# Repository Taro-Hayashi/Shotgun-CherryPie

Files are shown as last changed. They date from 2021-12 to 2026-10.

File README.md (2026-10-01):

# Shotgun チェリーパイ ビルドガイド（[English](https://github.com/Taro-Hayashi/Shotgun-CherryPie/blob/main/README_EN.md)）
- [キット内容](#キット内容)
- [準備](#準備)
- [はんだ付け](#はんだ付け)
- [組み立て](#組み立て)
- [キーのカスタマイズ](#キーのカスタマイズ)
- [3Dプリンタ製カバーの組み立て](#3Dプリンター製カバーの組み立て)
- [その他](#その他)

## キット内容
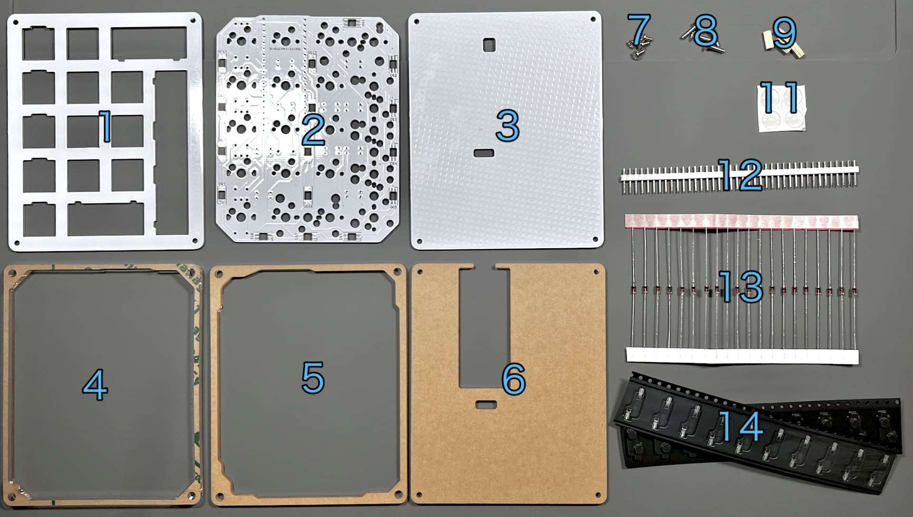
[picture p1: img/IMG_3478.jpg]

||部品名|数| |
|-|-|-|-|
|1|メインボード|1||
|2|トッププレート|1||
|3|ボトムプレート|1||
|4|ミドルプレート1|1~2|5mm厚か3mm厚|
|5|ミドルプレート2|1|3mm厚|
|6|ミドルプレート3|1|3mm厚|
|7|ネジ（短）|4|4mm|
|8|ネジ（長）|4|8mm|
|9|スペーサー|4||
|11|ゴム足|4||
|12|40Pピンヘッダ|1||
|13|ダイオード|20|1N4148|
|14|Cherry MX ホットスワップソケット|20||
|15|3Dプリンター製カバー|1||
||Raspberry Pi Pico（Type-C、互換品）|1|遊舎工房キットのみ|

2026年8月より遊舎工房さん取り扱いキットではRaspberry Pi Pico（Type-C）互換品が同梱されています。

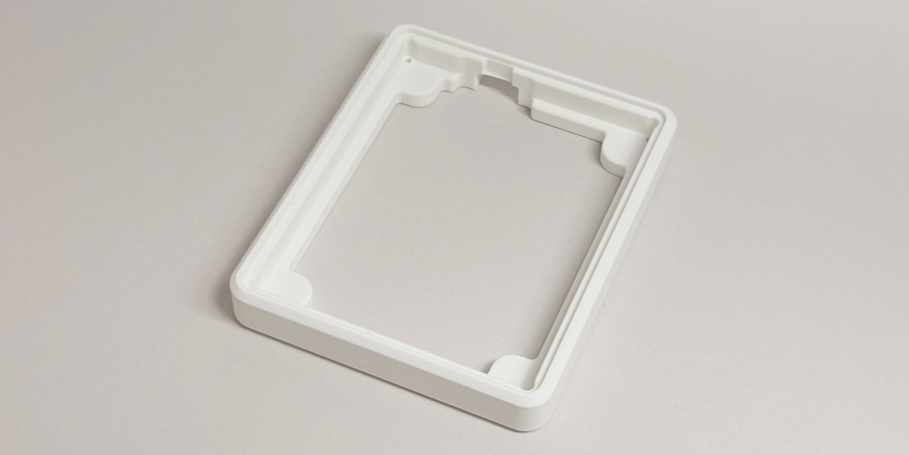
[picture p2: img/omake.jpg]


Step
- https://github.com/Taro-Hayashi/Shotgun-CherryPie/tree/main/step

### キット以外に必要なもの

リンクにはアフィリエイトリンクを含みます。

|部品名|数||
|-|-|-|
|キースイッチ（[遊舎工房](https://shop.yushakobo.jp/collections/cherry-mx-clone)、[TALPKEYBOARD](https://shop.talpkeyboard.com/collections/keyswitch?ref=tarohayashi)）|〜20|CherryMX互換|
|キーキャップ（[遊舎工房](https://shop.yushakobo.jp/collections/keycaps)、[TALPKEYBOARD](https://shop.talpkeyboard.com/collections/keycaps?ref=tarohayashi)）|〜20|スイッチに合うもの|
|USB ケーブル|1|データ転送対応のもの|
|Raspberry Pi Pico（同梱でない場合）|1|互換品には適合しないものがあります。|

### オプション

|部品名|数||
|-|-|-|
|スタビライザー（[遊舎工房](https://shop.yushakobo.jp/products/a0500st)）|必要数|2U、PCBマウント|
|ロータリーエンコーダー（[遊舎工房](https://shop.yushakobo.jp/products/3762)）|～5|EC11/EC12/ロープロファイル|
|ノブ（[遊舎工房](https://shop.yushakobo.jp/products/3733)）|〜5|外径19mmまで|
|LED SK6812MINI-E（[遊舎工房](https://shop.yushakobo.jp/products/sk6812mini-e-10)）|12、もしくは28|12個で裏面のみ、28個で両面|

### 必要な工具
|工具名|
|-|
|はんだごて|
|はんだ|
|ピンセット|
|精密ドライバー|
|ニッパー等ダイオードの足を切れるもの|

## 準備
### レイアウトを決める
このキットはいろいろなレイアウトから選んでお使いいただけます。
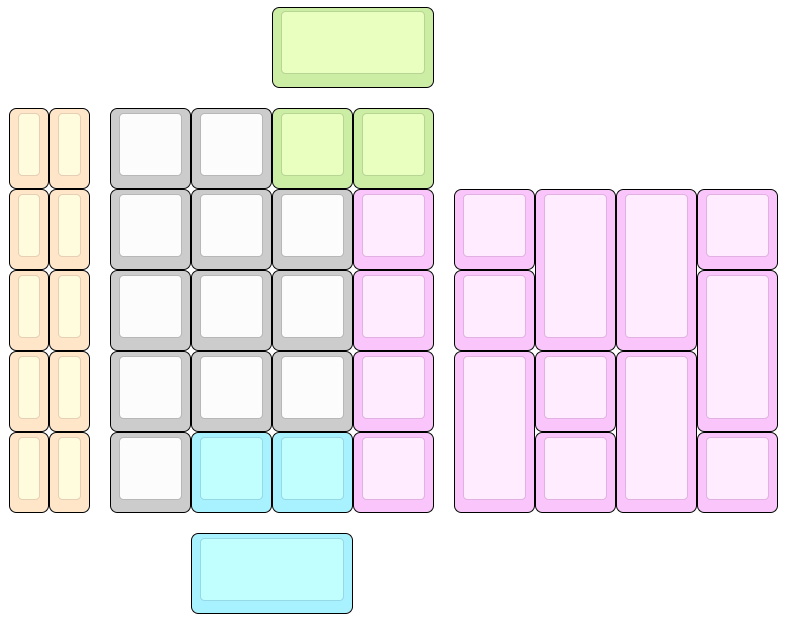
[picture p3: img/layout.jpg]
  
色のついているところが交換可能になっています。  

ビルドガイドではロータリーエンコーダーを1つ、幅が2倍（2U）のキーを二つ使ったテンキーにします。  
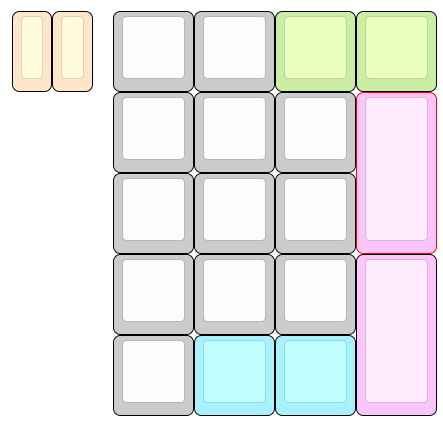
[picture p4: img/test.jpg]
    
キット、その他必要なものに追加でロータリーエンコーダーとノブを一つずつ、スタビライザーを2つ用意しました。  
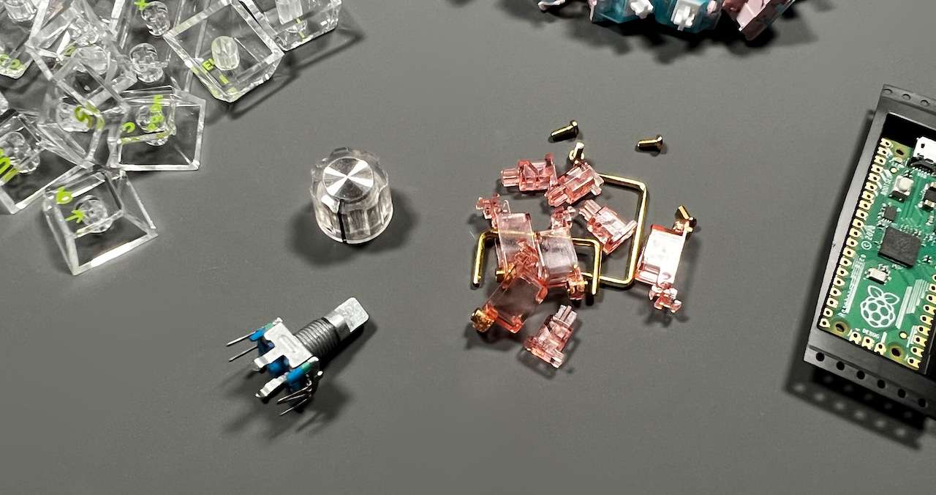
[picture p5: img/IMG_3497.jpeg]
    

### テスト用ファームウェアの書き込み
こちらからテスト用ファームウェアをダウンロードしてください。
 - https://github.com/Taro-Hayashi/Shotgun-CherryPie/releases/latest/download/tarohayashi_shotgun_cp_default.uf2

Raspberry Pi Picoを、BOOTSELボタン押しながらUSBケーブルでPCと接続すると、RPI-RP2というUSBメモリとして認識されます。
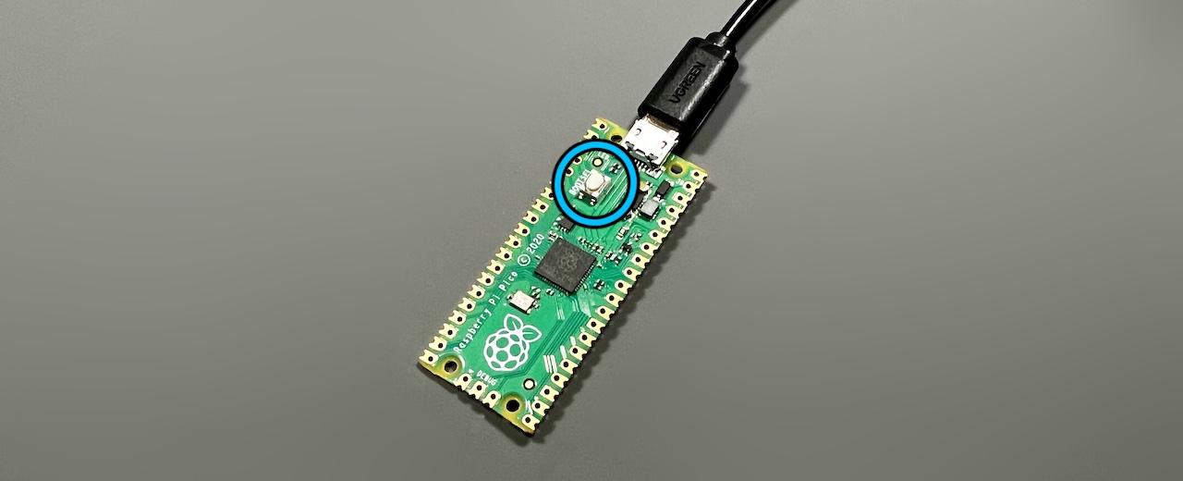
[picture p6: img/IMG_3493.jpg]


ここにダウンロードしたuf2ファイルを書き込むと、Raspberry Pi Picoをキーボードとして使えるようになります。

書き込みが終わったら一旦USBケーブルは外します。

## はんだ付け
はんだ付けのやり方は動画で見るとわかりやすいです。
パーツは思ったより壊れないので落ち着いて作業すると失敗しにくいです。

 - ホームセンターのDCMさんの解説動画(58秒～)

(https://www.youtube.com/watch?v=JFQg_ObITYE&t=58s)

### LEDのはんだ付け（オプション）
LEDを取り付ける場合はメインボードに最初にはんだ付けします。
 - [LEDの取り付け方](led.md)

後からでも可能ですが他の部品にこてが当たり溶かしてしまう可能性があります。

### ダイオードのはんだ付け

D1~D20まで取り付けます。
足を曲げて裏から差し込みます。
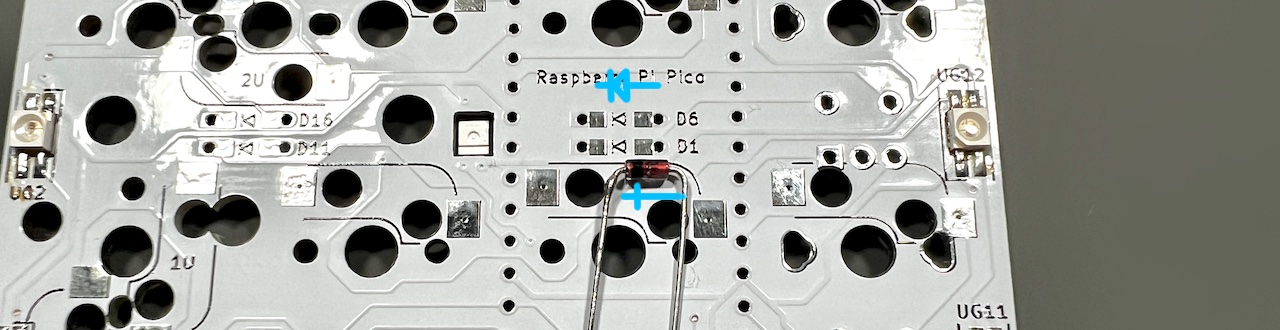
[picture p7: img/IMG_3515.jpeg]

ダイオードには向きがあります。三角形の先の棒と黒線を合わせましょう。

表で更に足を曲げて抜けないようにします。
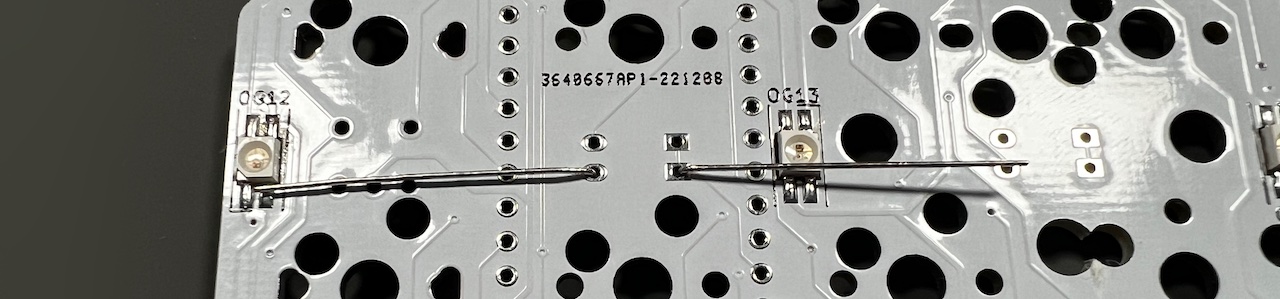
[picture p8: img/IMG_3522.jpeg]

ダイオードと並行に曲げるとあとでキースイッチに干渉しにくいです。

はんだ付けをして足を切ります。
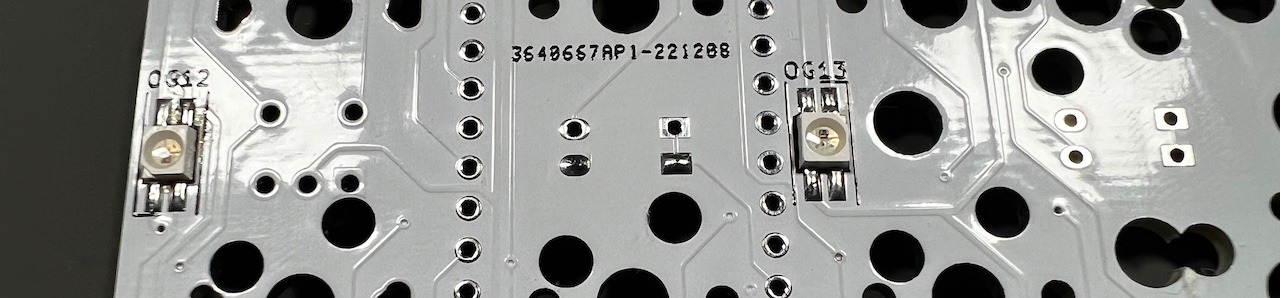
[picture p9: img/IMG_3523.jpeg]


### ソケットのはんだ付け
使うソケットのパッドにソケットを乗せます。
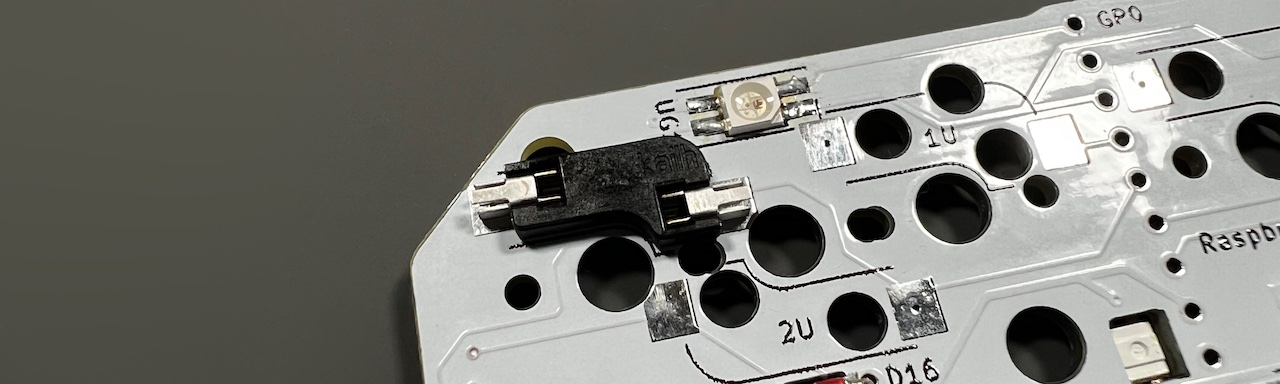
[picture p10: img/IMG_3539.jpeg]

ソケットを置いたらピンセットで押さえつけながらはんだを注いでいきます。入り組んでいて表面積が多いので多めに必要になります。
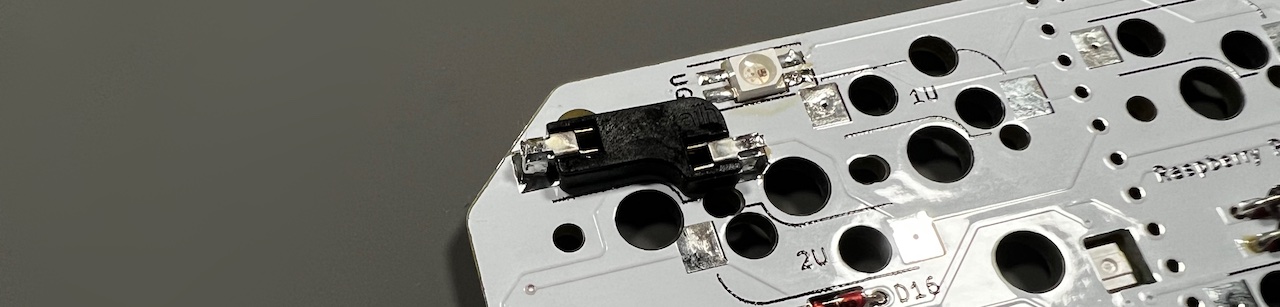
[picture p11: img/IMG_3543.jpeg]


裏から見ると左右が逆になっているのでレイアウトに注意してソケットの位置を決めます。
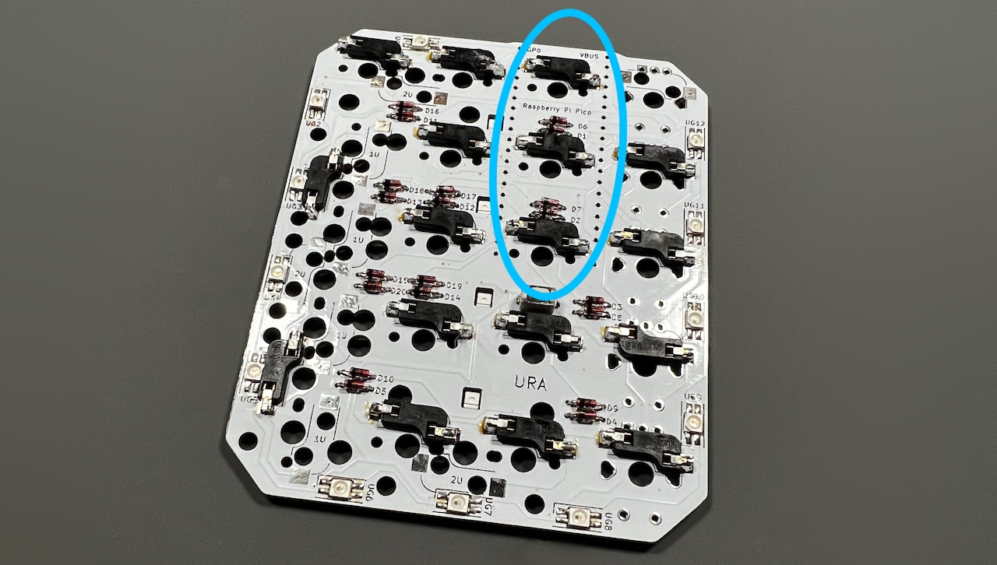
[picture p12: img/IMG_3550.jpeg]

青枠の部分にあるソケットは基板になるべく密着するようにはんだ付けしてください。

### （オプション）ロータリーエンコーダーのはんだ付け
足を折らないようにホールに通します。
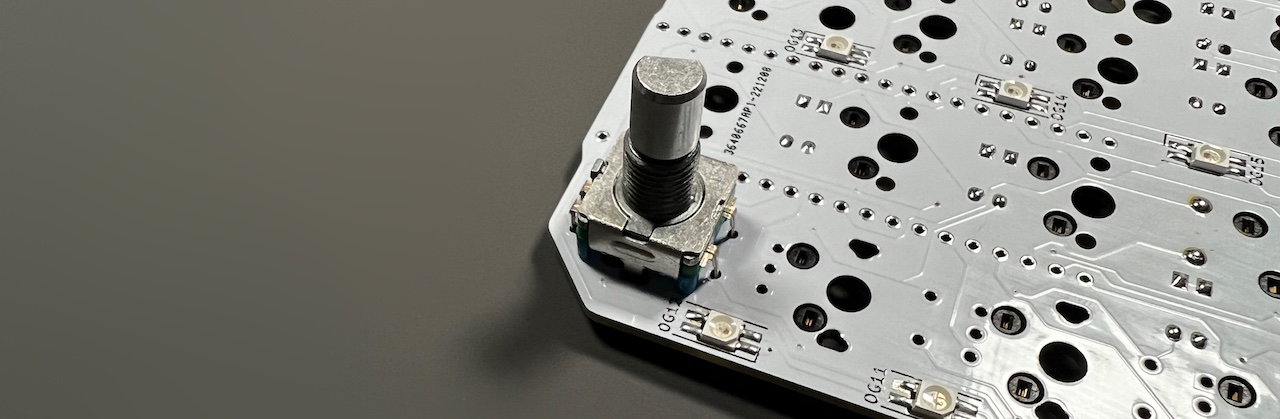
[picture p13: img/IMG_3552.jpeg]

あとで場所を変更する可能性があるときはクリップの部分ははんだ付けしなくても大丈夫です。
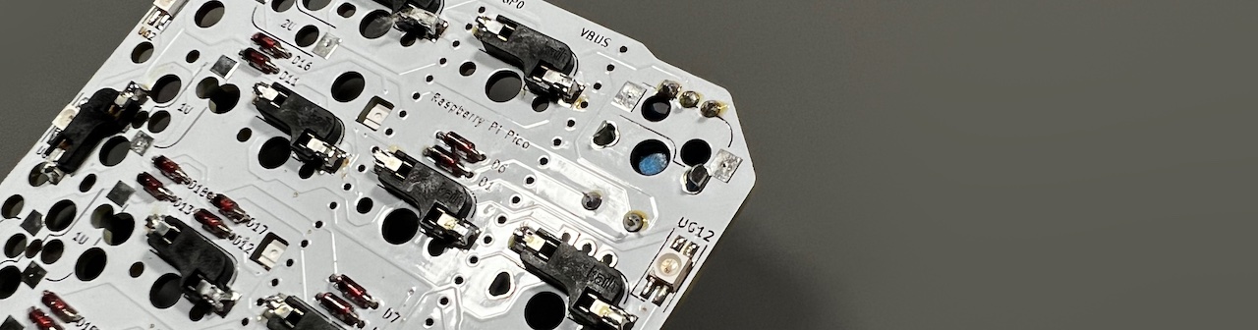
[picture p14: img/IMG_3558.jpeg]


### Raspberry Pi Picoのはんだ付け
ピンヘッダを20ピンずつに切るか折るかします。
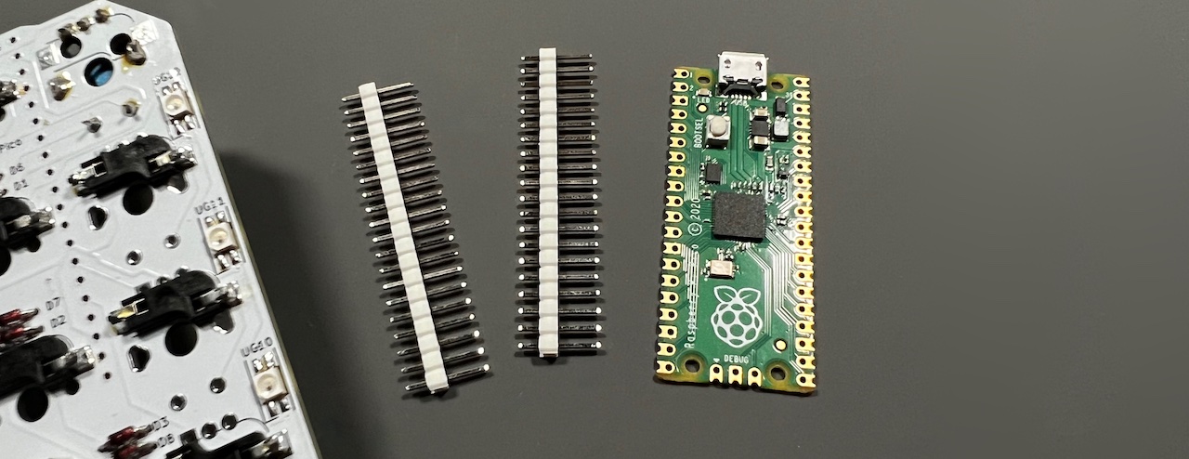
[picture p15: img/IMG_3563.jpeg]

Raspberry Pi Picoを取り外せなくなるので隠れてしまうダイオードの方向やソケットのはんだ付けを改めて確認してください。

ピンヘッダを基板に立てます。どちら側でも構いませんが長い方を挿しました。
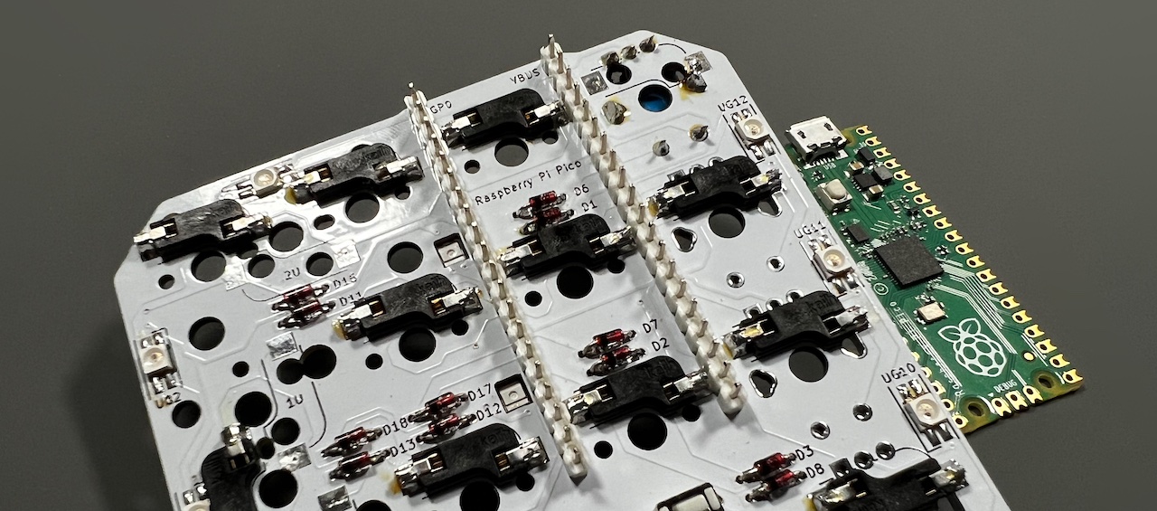
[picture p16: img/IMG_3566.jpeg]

GP0、VBUS位置を合わせてRaspberry Pi Picoを乗せ、はんだ付けします。
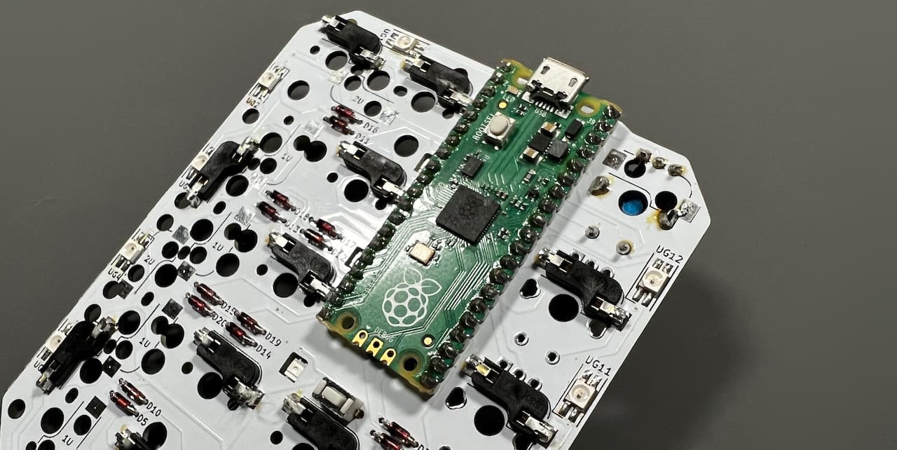
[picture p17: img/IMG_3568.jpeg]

表面の足を切りはんだ付けします。
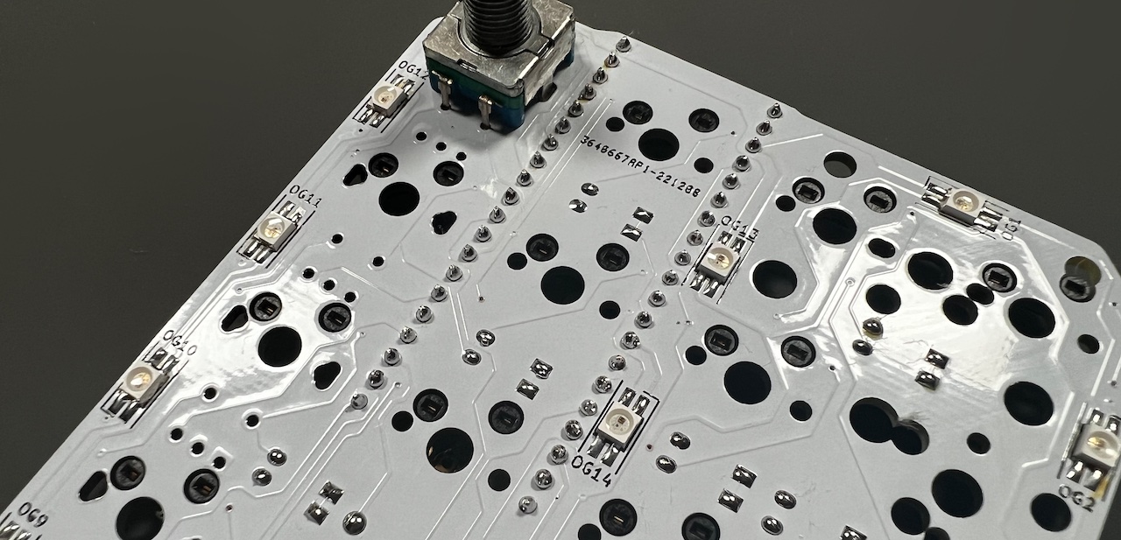
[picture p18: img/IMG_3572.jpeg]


### 動作確認
Raspberry Pi PicoにUSBケーブルを繋ぎます。
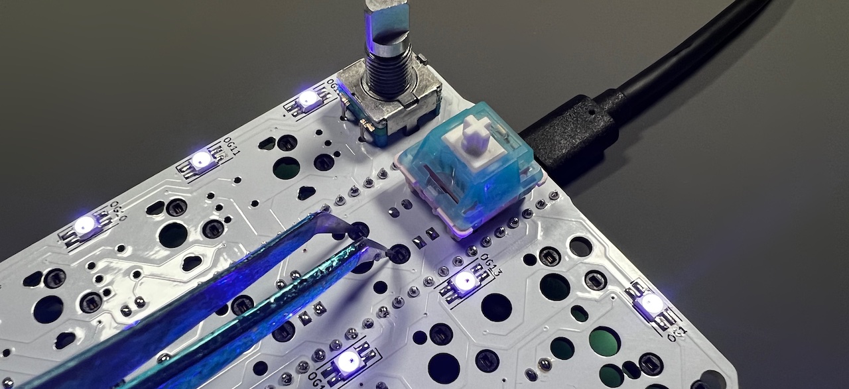
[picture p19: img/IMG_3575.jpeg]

ソケットをピンセットで短絡したり、スイッチを挿して押したりしてキーが入力されるか調べます。

問題がなければはんだ付けは終了です。お疲れ様でした。

## 組み立て
### （オプション）スタビライザーの組み立てと取り付け
スタビライザーがあると2Uのキーの押下が安定します。無くても使えるのでお好みでお使いください。

小さい方のパーツの穴が二つ開いている側を、大きいパーツの穴が開いている方向に合わせて組み合わせます。
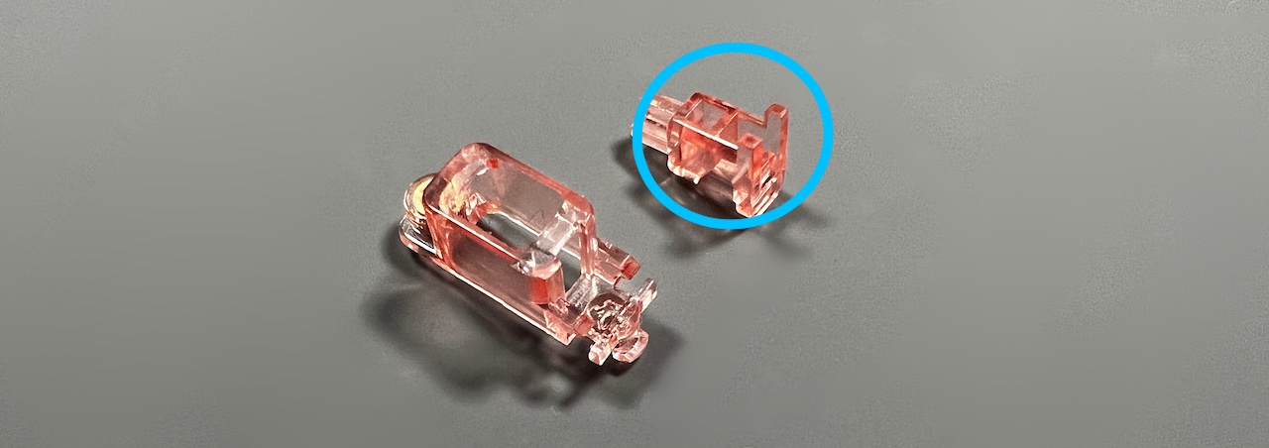
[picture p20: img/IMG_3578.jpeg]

金属の棒を下の穴に差し込みツメにパチっと音がするまで押し込んで完成です。
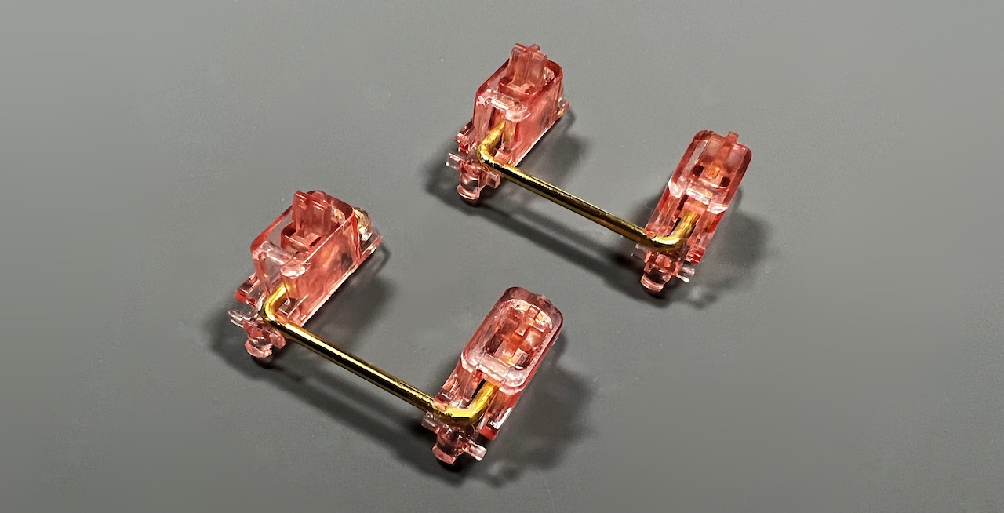
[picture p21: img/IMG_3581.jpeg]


基板の大きい方の穴にツメをひっかけながら取り付けます。
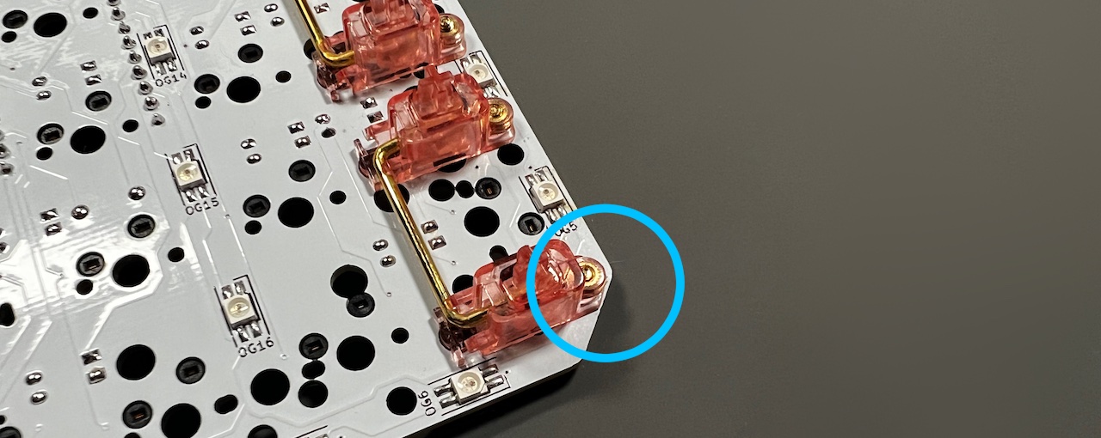
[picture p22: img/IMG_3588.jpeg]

角にスタビライザーを付けるとケースと干渉するためニッパーで切り落としています。

### プレートの取り付け
傷が付かないように裏返しに組み立てられて梱包されているので一度すべてのネジ、スペーサーを外してください。
アクリルプレートからは保護フィルムをはがします。割れやすいパーツもあるので気をつけてください。

メインボードにトッププレートを乗せます。裏表、上下左右に気を付けましょう。

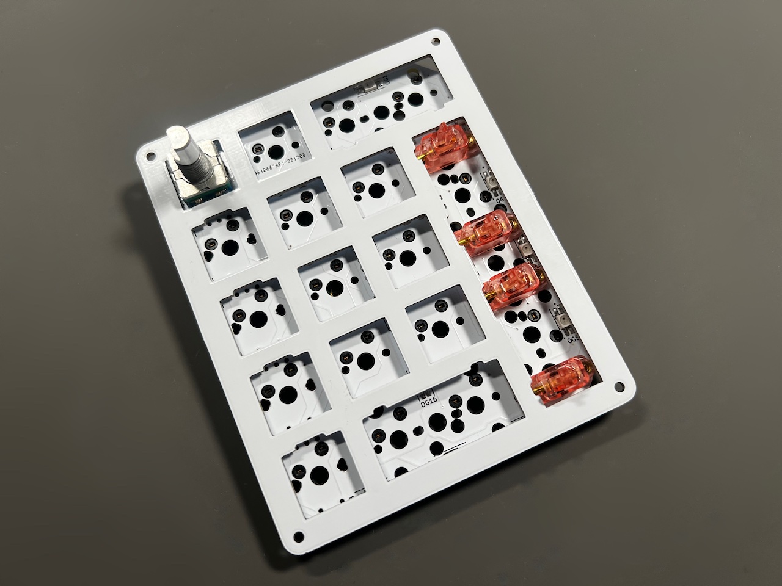
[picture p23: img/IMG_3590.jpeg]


隅のキースイッチから差し込んで、トッププレートにツメを咬ませます。
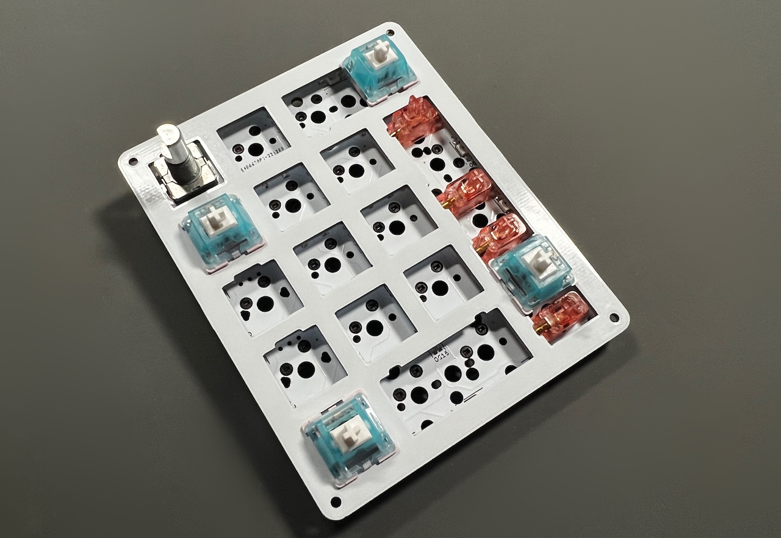
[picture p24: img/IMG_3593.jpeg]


全てのスイッチを取り付けました。
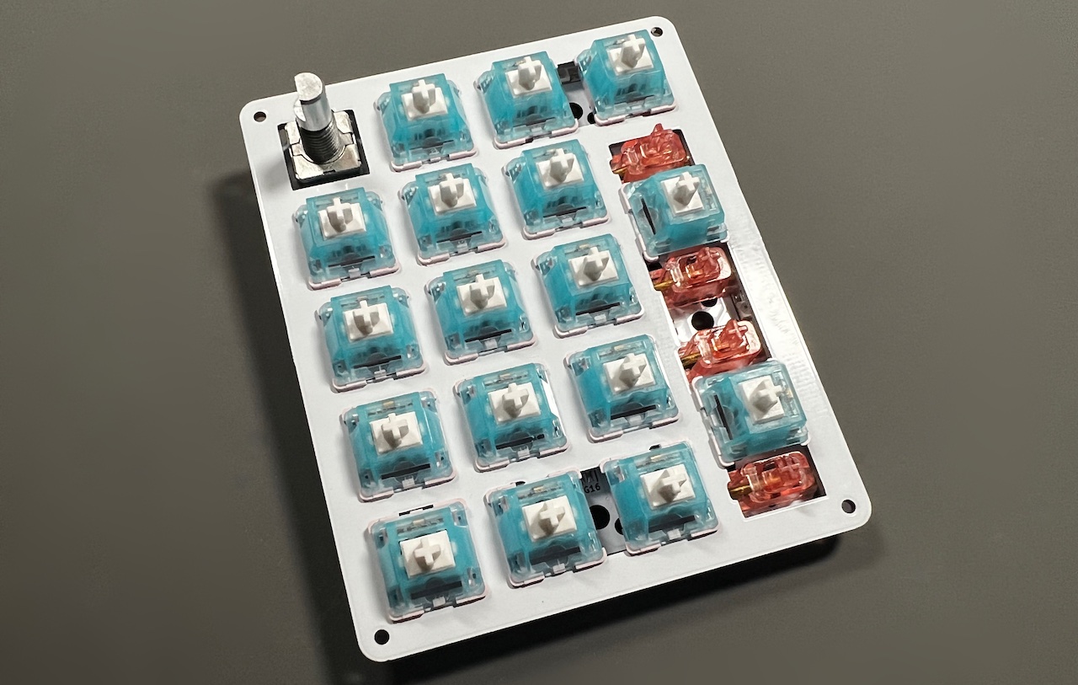
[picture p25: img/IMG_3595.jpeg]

トッププレートは浮いていますが、スイッチのツメに引っかかっているため安定しているはずです。

裏返して4隅にスペーサーを、ネジ（短）で取り付けます。
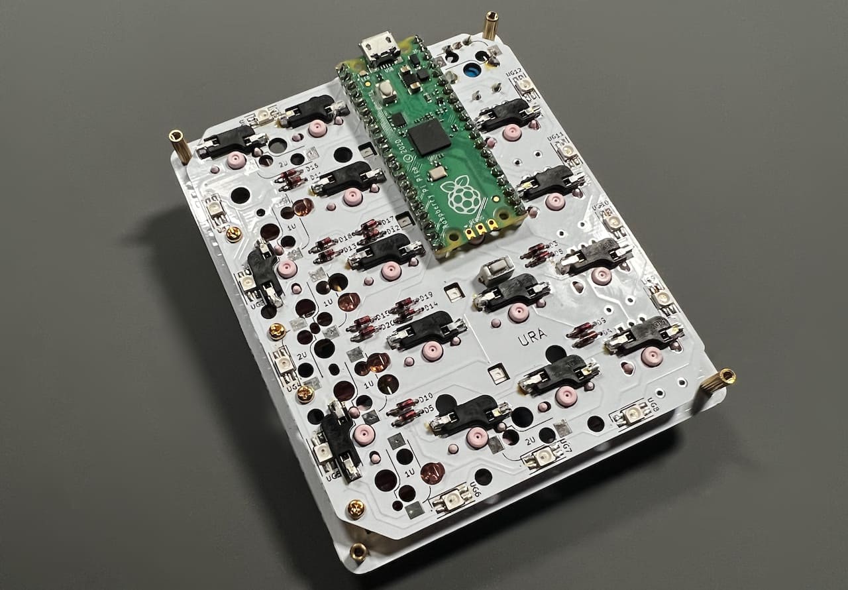
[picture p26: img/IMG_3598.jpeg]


ミドルプレート1（5mm厚1枚、もしくは3mm厚が2枚、穴が長方形に近い）、ミドルプレート2（3mm厚、穴が少し狭い）の順にスペーサーに通します。

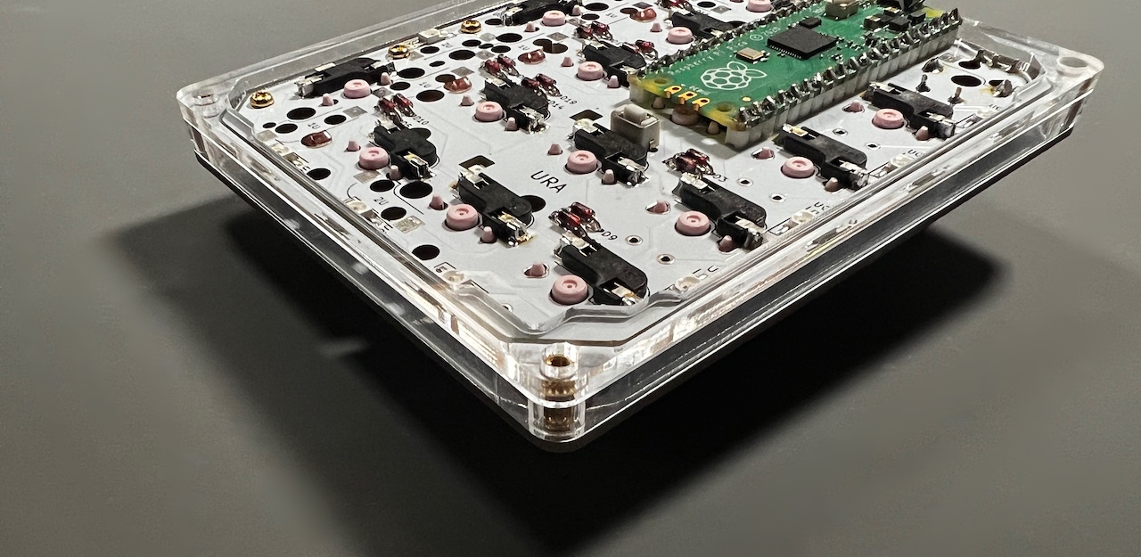
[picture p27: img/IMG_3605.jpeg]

Raspberry Pi PicoのUSB端子を避ける時に割れないように気を付けてください。

ミドルプレート3を乗せます。
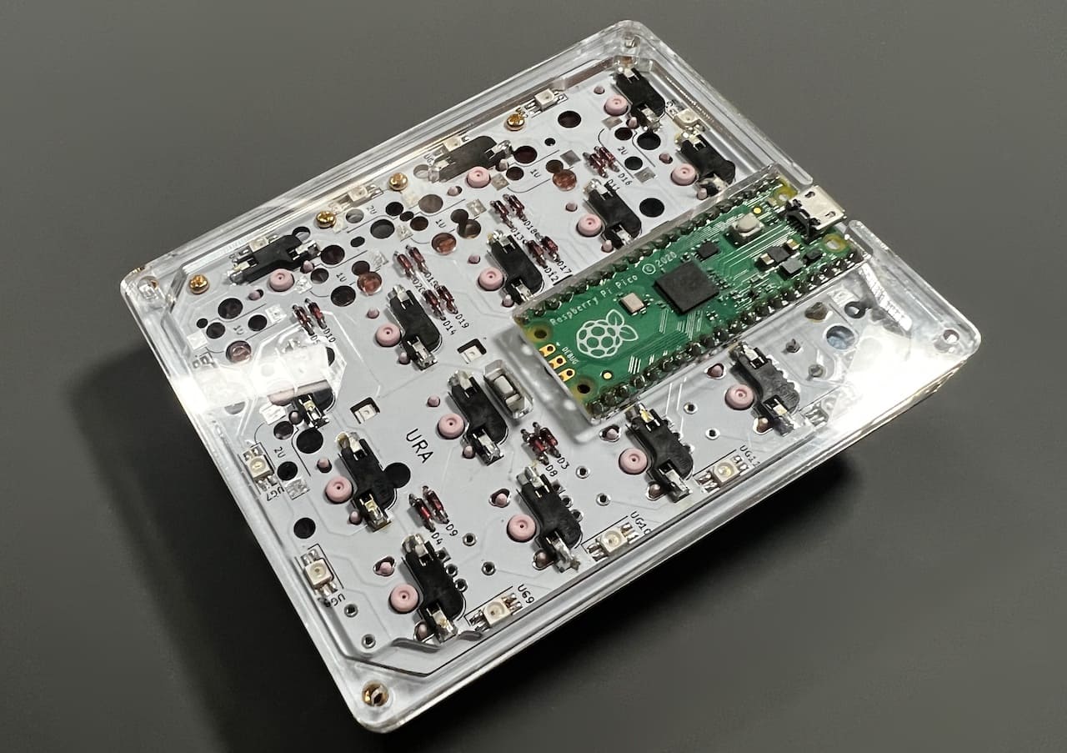
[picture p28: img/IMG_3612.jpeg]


バックプレートをネジ（長）で組付けてゴム足を4隅に貼ります。
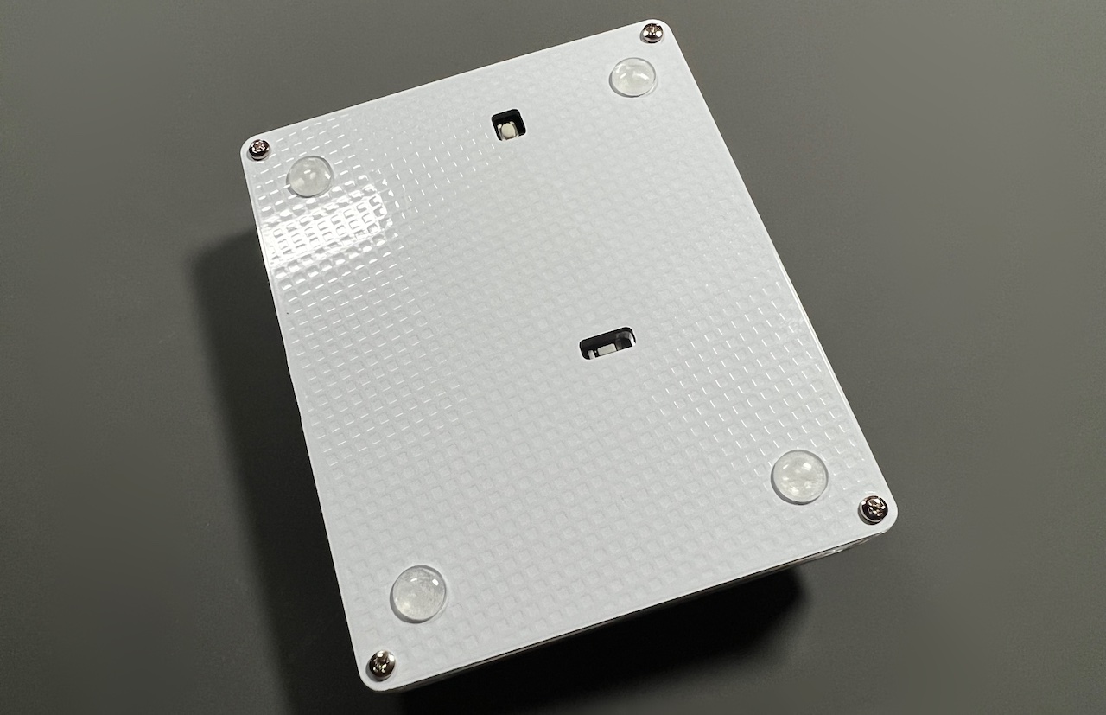
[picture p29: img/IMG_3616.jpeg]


キーキャップを乗せたら組み立ては終了です。
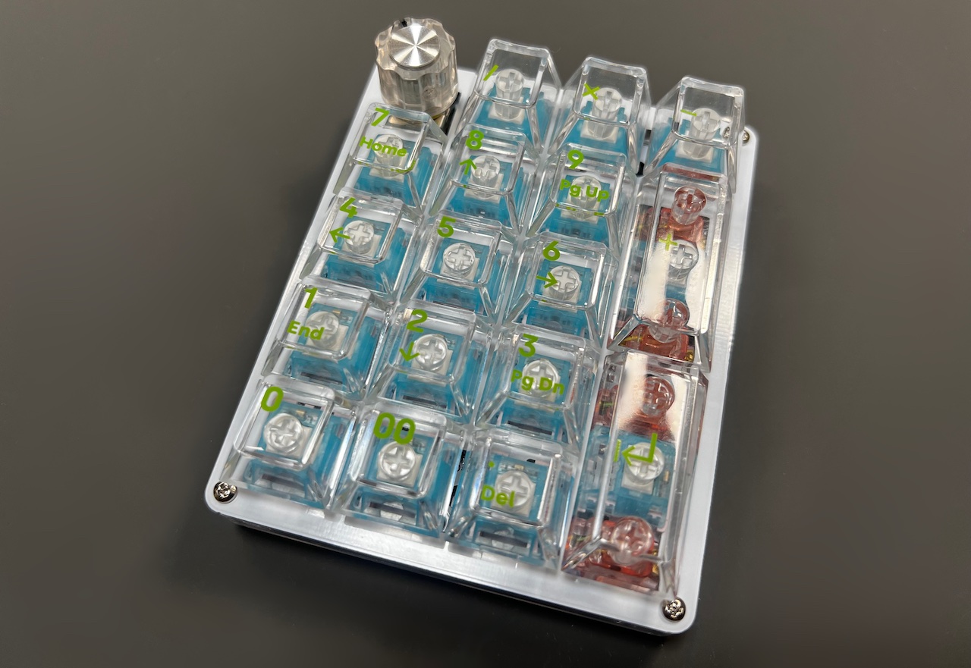
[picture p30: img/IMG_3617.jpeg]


早速USBケーブルでPCと接続してRemap用ファームウェアを書き込みましょう。
 - https://github.com/Taro-Hayashi/Shotgun-CherryPie/releases/latest/download/tarohayashi_shotgun_cp_via.uf2

裏面のスリットからリセットボタンを押すか、USBのすぐ下のキーを押しながらケーブルを接続して2秒待ってから離すとRPI-RP2フォルダを出すことができます。

## キーのカスタマイズ
RemapにGoogle ChromeかMicrosoft Edgeでアクセスしてください。
- Remap https://remap-keys.app

左を選んで進んでいくとアドレスバーからメッセージが出てキーボードを選択できます。
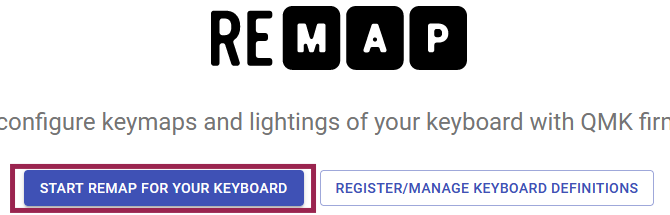
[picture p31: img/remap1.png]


ドラッグアンドドロップでキーマップの変更が終わったら右上のflashボタンを押すと反映されます。


### キーのサイズを合わせる
レイアウトオプションから2Uキーの設定をすることができます。
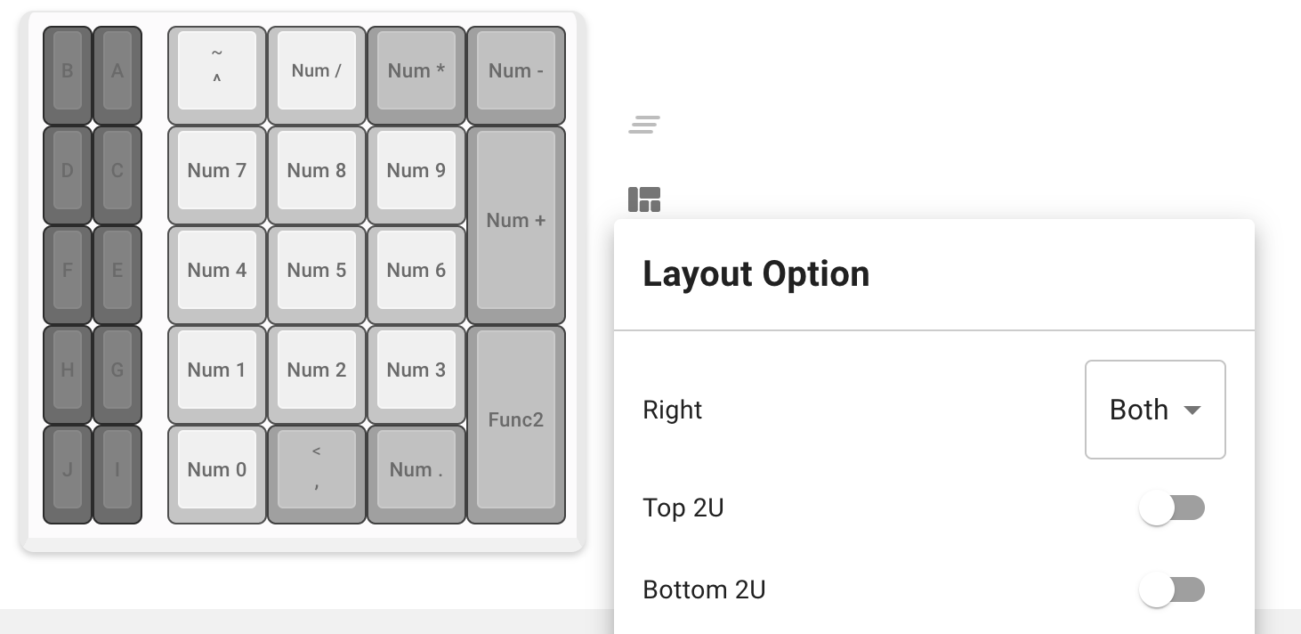
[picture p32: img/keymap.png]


### 特殊なキーを設定する
FUNCTIONSタブのVIA USER KEYにあらかじめ用意されたショートカットキーがあります。
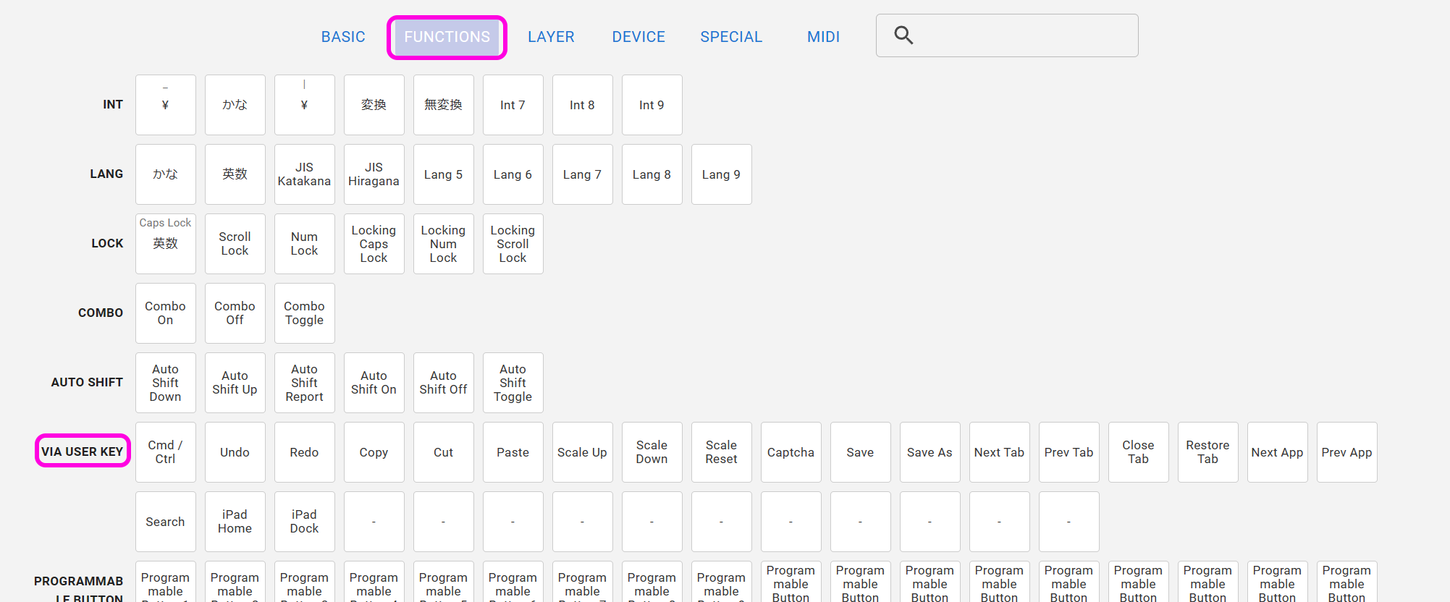
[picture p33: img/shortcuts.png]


### キーマップの保存と復元
⇔アイコンで作ったキーマップを保存することができます。
いくつかサンプルをご用意しました。自分のレイアウトを公開することもできるので是非お試しください。
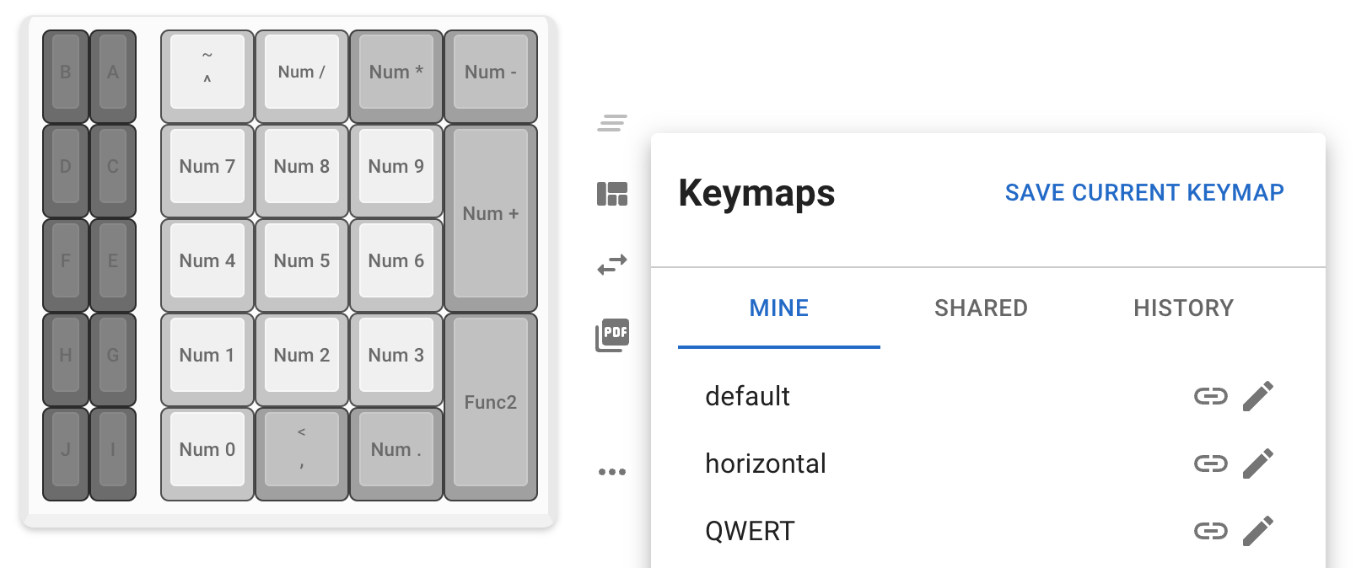
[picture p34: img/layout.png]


## 3Dプリンター製カバーの組み立て
お好みで3Dプリンター製のカバーもご利用いただけます。
スイッチプレートに短いネジでスペーサーを付けた状態にします。
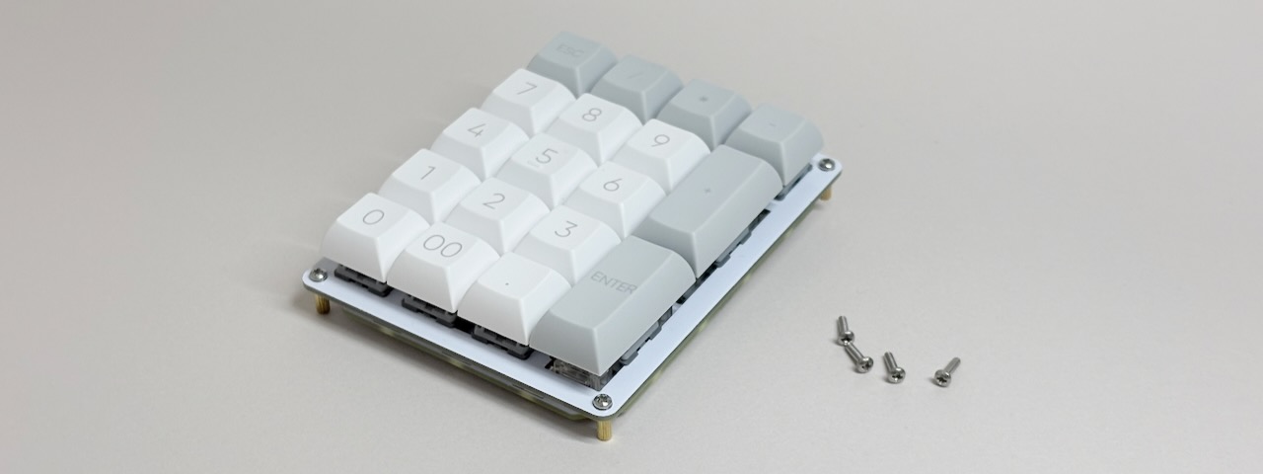
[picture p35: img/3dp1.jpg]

ケースに入れて裏面でネジ止め、ゴム足を貼ります。
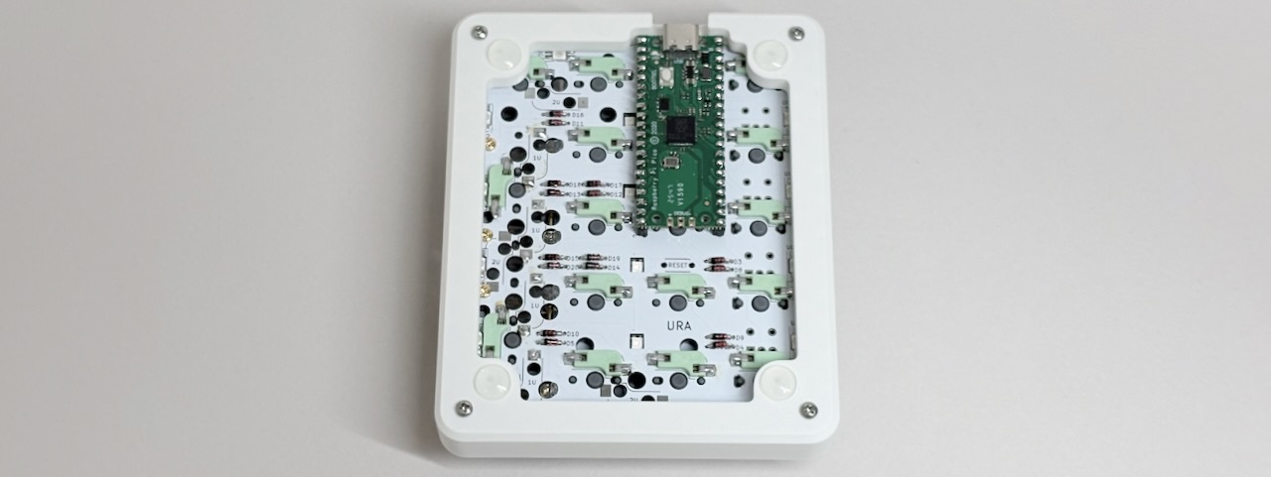
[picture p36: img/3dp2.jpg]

完成です。
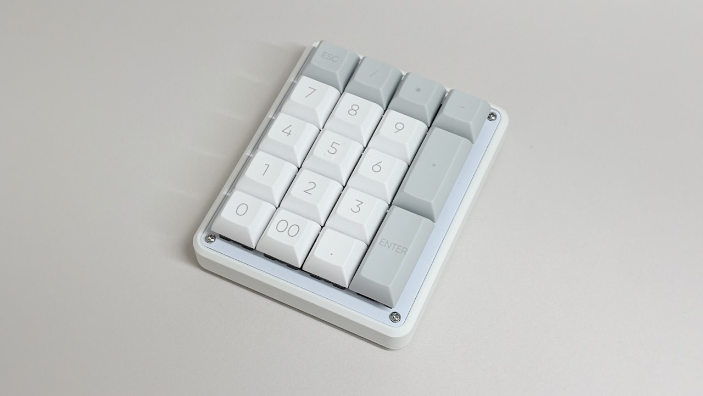
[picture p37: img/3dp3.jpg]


## その他

### PRK Firmware
Paspberry Pi Picoをキーボードとして扱う方法は他にも複数あります。PRK Firmwareはその一つでキー入れ替えの試行錯誤が手軽なところが特徴です。
- [PRK Firmware](https://github.com/picoruby/prk_firmware/)

### ファームウェアのコード
 - [qmk_firmware](qmk_firmware)

### 3Dプリント製カバーのデータ
- https://github.com/Taro-Hayashi/Shotgun-CherryPie/tree/main/step

### プレートのデータ
 - [shotgun_cp_plates.zip](https://github.com/Taro-Hayashi/Shotgun-CherryPie/releases/latest/download/shotgun_cp_plates.zip)

### アクリル積層ケース
 - [Shotgun チェリーパイ アクリル積層ケース](AcrylicCase/README.md)

### 謝辞
foostan様のフットプリントを流用、改変して使わせていただきました。
https://github.com/foostan/kbd/
https://github.com/foostan/kbd/blob/master/LICENSE

yoichiro様のフットプリントを流用、改変して使わせていただきました。
https://github.com/yoichiro/yoichiro-kbd
https://github.com/yoichiro/yoichiro-kbd/blob/main/LICENSE

せきごん様がGPIO15を使っている場合でも正常に動くようにしてくださいました。
https://github.com/sekigon-gonnoc/qmk_firmware/tree/rp2040

hasumikin様がPRK Firmwareでロータリーエンコーダーを複数個使用できるようにして、感度も上げてくださいました。
https://github.com/picoruby/prk_firmware/

### 販売サイト
- BOOTH: https://tarohayashi.booth.pm/items/3430753
- 遊舎工房: https://shop.yushakobo.jp/products/3415

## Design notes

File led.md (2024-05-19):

## LEDの取り付け方
  
裏面だけ光らせたい場合はUG1～12の12個、表面も光らせたい場合はOG1～16も合わせた28個をはんだ付けします。  
  
端子同士がくっつきやすいので、LEDのはんだ付けにはフラックスを使います。  
はんだ付けの難易度がとても下がるため私はLED以外にも毎回使っています。  
ベタつくのでフラックスクリーナーやIPA（イソプロピルアルコール）で掃除をすると綺麗になります。  
  
まずは裏面のUG1～12を取り付けます。  
LEDの切り欠きとシルク印刷のコーナーを合わせてはんだ付けしましょう。  
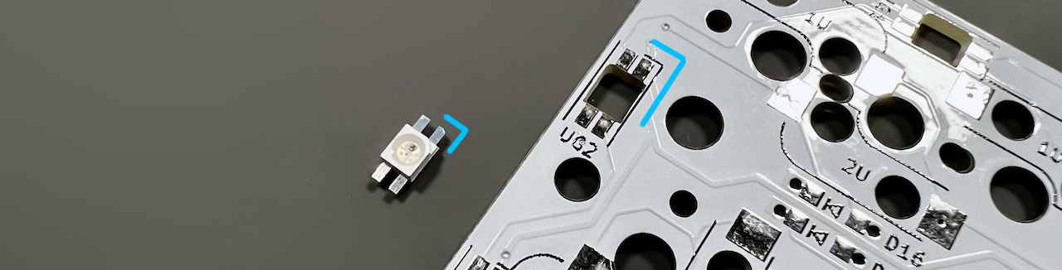
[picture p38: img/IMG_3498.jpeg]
    
向きがバラバラなので毎回確認してください。方向を間違えるとショートしてしまってキーボード自体が動きません。  

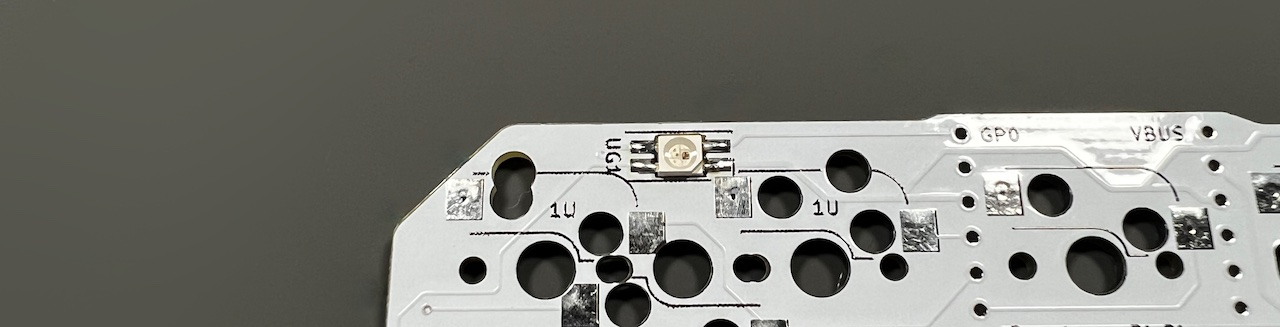
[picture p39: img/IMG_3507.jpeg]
    
両側のランドにはんだを乗せやすいようにLEDは中央に置くことを意識するといいと思います。  

裏面が終わったら表面のOG1～16を取り付けます。  
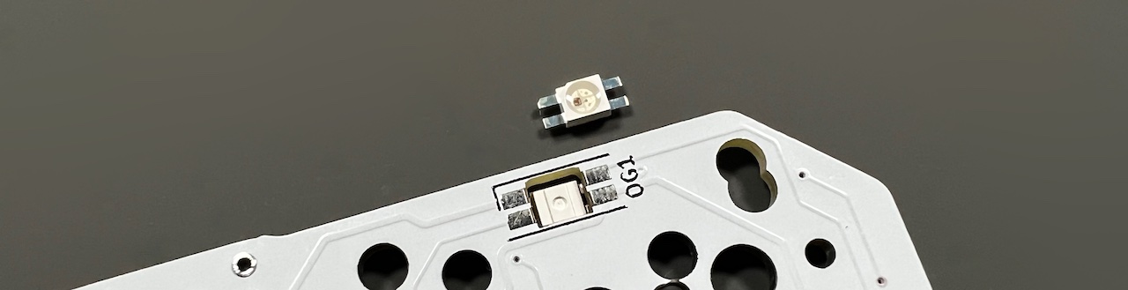
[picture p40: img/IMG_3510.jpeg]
  
一部はUGと共通の穴を使っています。  

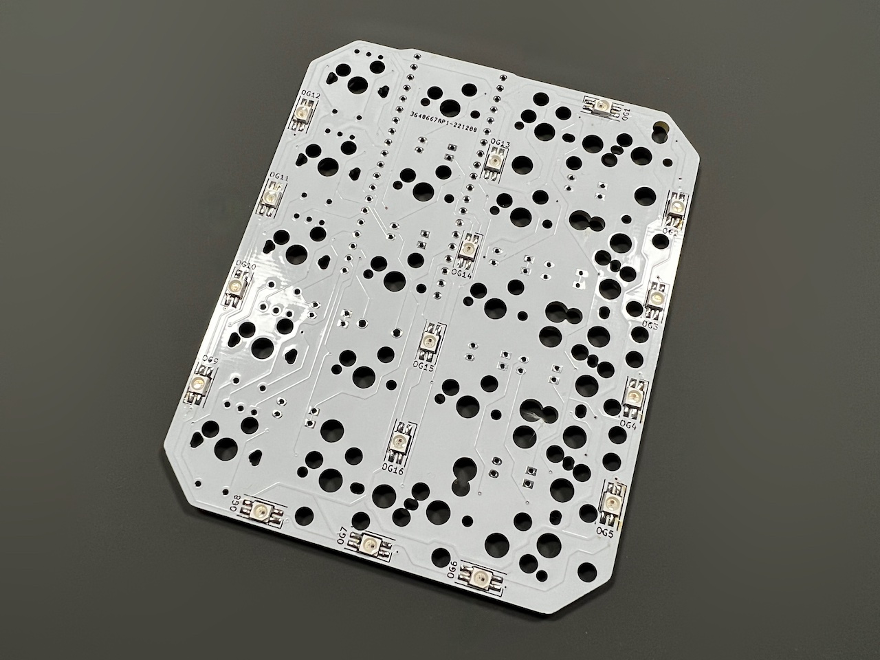
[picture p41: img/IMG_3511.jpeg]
  
  
ブラウザの機能で戻ってください。

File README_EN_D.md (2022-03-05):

# Shotgun チェリーパイ Build Manual（[日本語](https://github.com/Taro-Hayashi/Shotgun-CherryPie/blob/main/README.md)）
- [Contens](#Contens)
- [Preparation](#Preparation)
- [Soldering](#Soldering)
- [Assembling](#Assembling)
- [Customise](#Customise)

## Contents
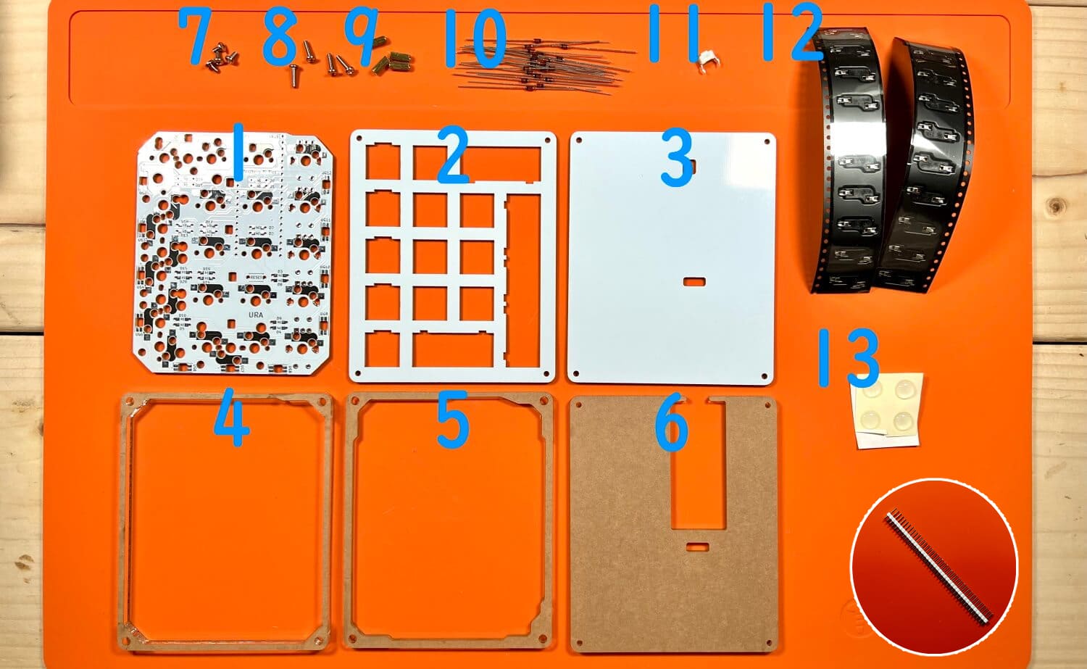
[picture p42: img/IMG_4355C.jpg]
  
||Name|Quamtities| |
|-|-|-|-|
|1|Mainboard|1|
|2|Top plate|1||
|3|Bottom plate|1||
|4|Middle plate #1|1||
|5|Middle plate #2|1||
|6|Middle plate #3|1||
|7|Short screws|4|4mm|
|8|Long screws|4|8mm|
|9|Spacers|4|8mm|
|10|Diodes|20|1N4148|
|11|Tactile switch|1||
|12|Hotswap socket|20||
|13|Rubber feet|4||
|-|Pin header|1||

### Additional required
|Name|Quantities|||
|-|-|-|-|
|Raspberry Pi Pico|1||[Yushakobo](https://shop.yushakobo.jp/en/products/raspberry-pi-pico)|
|Switches|11 - 20|Cherry MX|[Yushakobo](https://shop.yushakobo.jp/en/collections/all-switches/cherry-mx-%E4%BA%92%E6%8F%9B-%E3%82%B9%E3%82%A4%E3%83%83%E3%83%81)|
|Keycaps|11 - 20|Cherry MX|[Yushakobo](https://shop.yushakobo.jp/en/collections/keycaps/cherry-mx-%E4%BA%92%E6%8F%9B-%E3%82%AD%E3%83%BC%E3%82%AD%E3%83%A3%E3%83%83%E3%83%97)|
|Micro-USB Cable|1||[Yushakobo](https://shop.yushakobo.jp/en/products/usb-cable-micro-b-0-8m)|

### Optional
|Name|Quantities|||
|-|-|-|-|
|Conthrough|2|[Usage](https://github.com/Taro-Hayashi/Shotgun-CherryPie/blob/main/conthrough2_EN.md)|[Yushakobo](https://shop.yushakobo.jp/en/products/31?_pos=1&_sid=ca92edae3&_ss=r&variant=40815837610145)|
|Stabilizer||2U, PCB mounted|[Yushakobo](https://shop.yushakobo.jp/en/collections/all-keyboard-parts/Stabilizer)|
|Rotary emcoders||EC11/EC12||
|knobs||Outer diameter up to 19mm||
|SK6812MINI-E|28||[Yushakobo](https://shop.yushakobo.jp/en/products/sk6812mini-e-10)|

## Preparation
### Determine key layout  
This kit has a variety of layouts to choose from.  
   

In this manual, we use rotary encoder and 2 2U keys.  
    
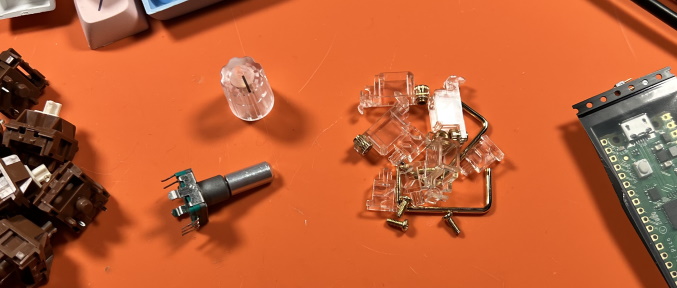
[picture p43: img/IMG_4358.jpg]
   

### Write firmware
Download PRK Firmware.
 - [Releases・picoruby/prk_firmware](https://github.com/picoruby/prk_firmware/releases)  

Click "Assets"
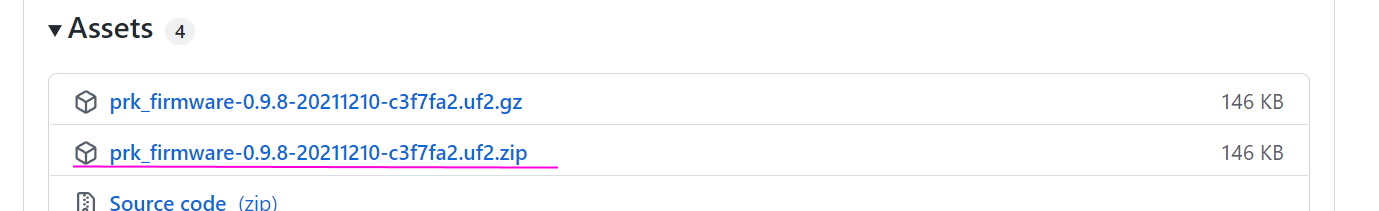
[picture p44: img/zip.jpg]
 

Connect the Raspberry Pi Pico to the PC while holding down the BOOTSEL button, it will be recognized as a USB memory device called RPI-RP2.    
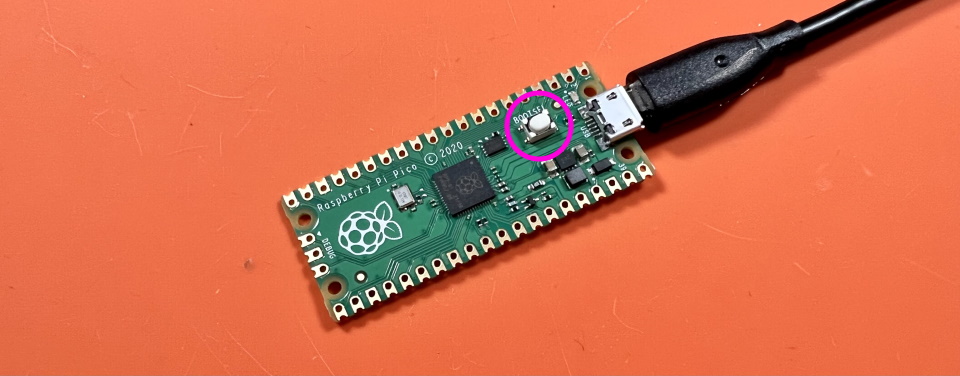
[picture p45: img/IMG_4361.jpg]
   
   
Writing the uf2 file, it will automatically reboot and be recognized as a drive called PRK Firmware.  
   
Drag and drop this keymap.rb onto the drive.
 - [keymap.rb](https://github.com/Taro-Hayashi/Shotgun-CherryPie/releases/download/0.1/keymap.rb)  

Detouch the USB cable.

## Soldering

### LED
If use LED, install first.  
 - [LED Installation](led_EN.md)  

### Diodes and tactile switch

Install the diodes from D1 to D20.
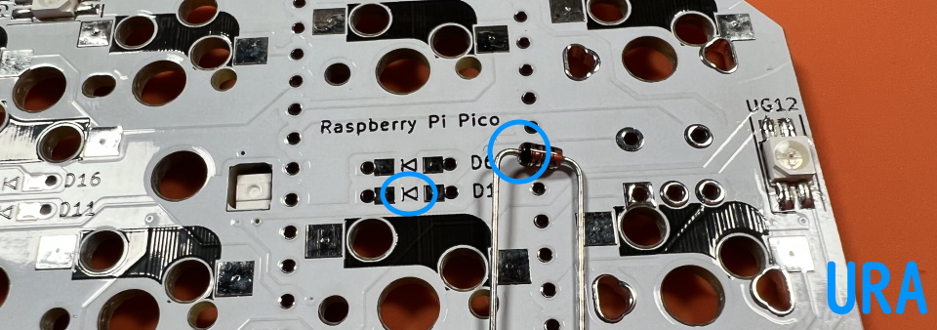
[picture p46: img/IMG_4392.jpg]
   
Diodes have a direction.  
  
Bend the legs parallel to the diode to prevent interference with the key switch later.  
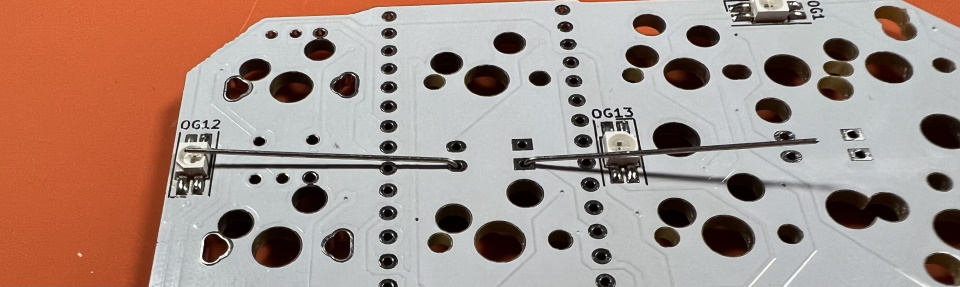
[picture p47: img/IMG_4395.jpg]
   
  
Solder and cut the legs.  
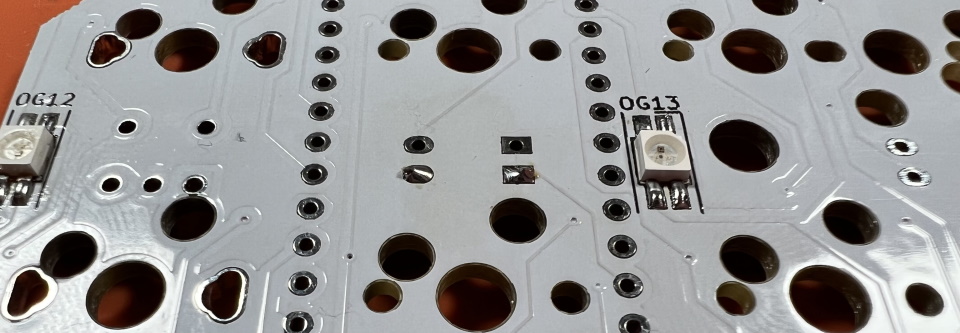
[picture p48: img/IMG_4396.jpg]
   
  
Solder Tactile Switches.   
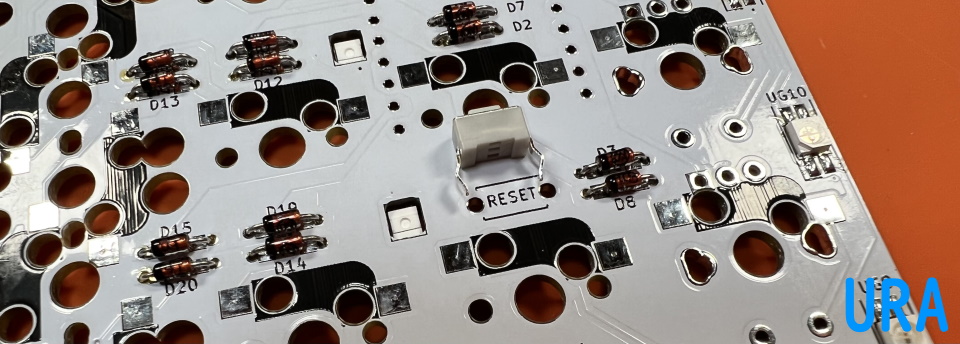
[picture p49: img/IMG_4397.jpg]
   

### Hotswap sockets
Apply a thin layer of solder beforehand.  
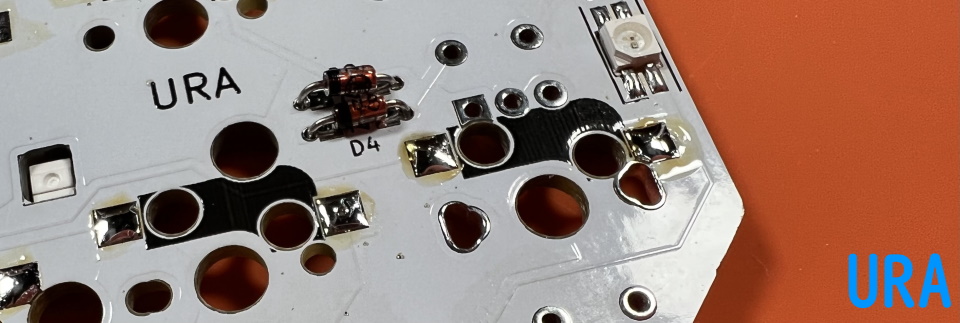
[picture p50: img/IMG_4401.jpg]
    
Solder sockets.  
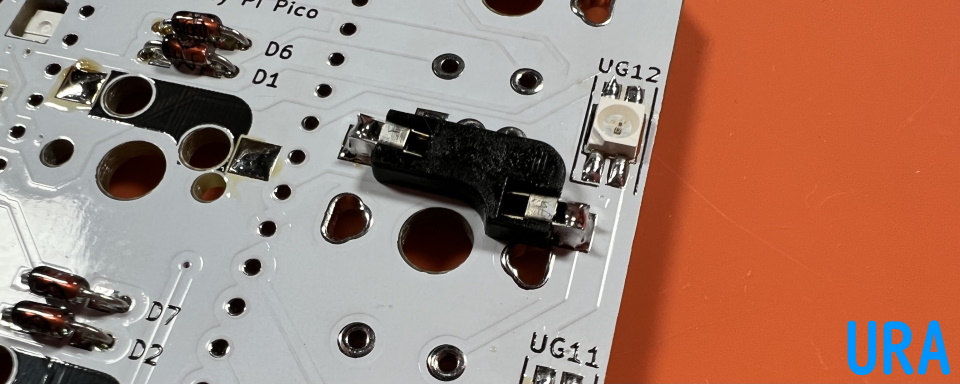
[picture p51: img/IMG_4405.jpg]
     

Be careful to keep the socket close to the board at the blue frame.  
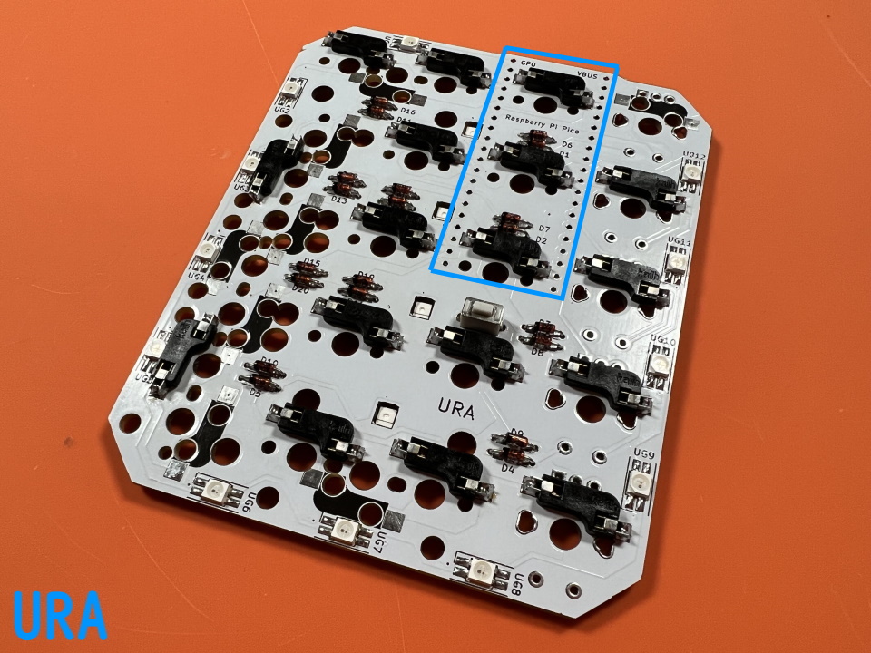
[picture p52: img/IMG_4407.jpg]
   

### Rotary encoder  
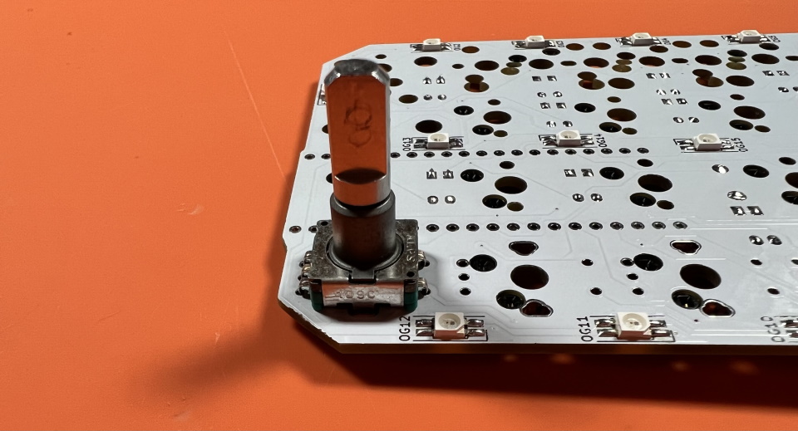
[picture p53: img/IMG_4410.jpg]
     
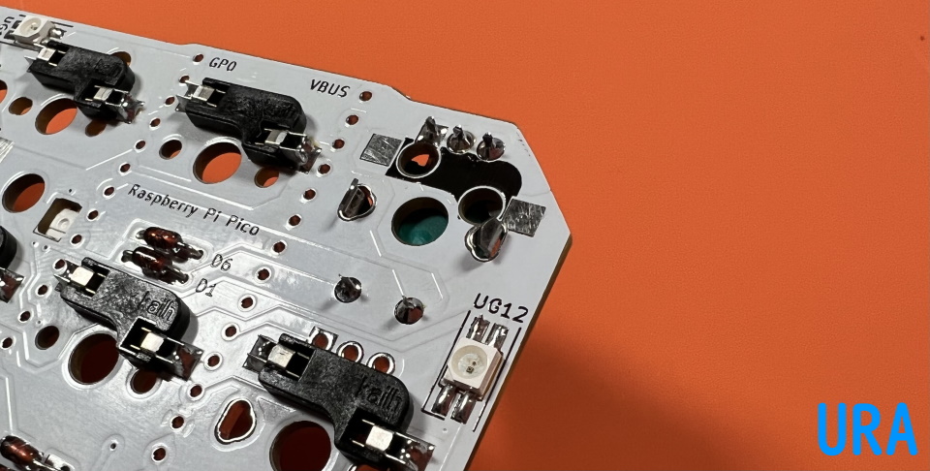
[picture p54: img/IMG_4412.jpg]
   

### Raspberry Pi Pico
Stand the pin header on the back side of the board.  
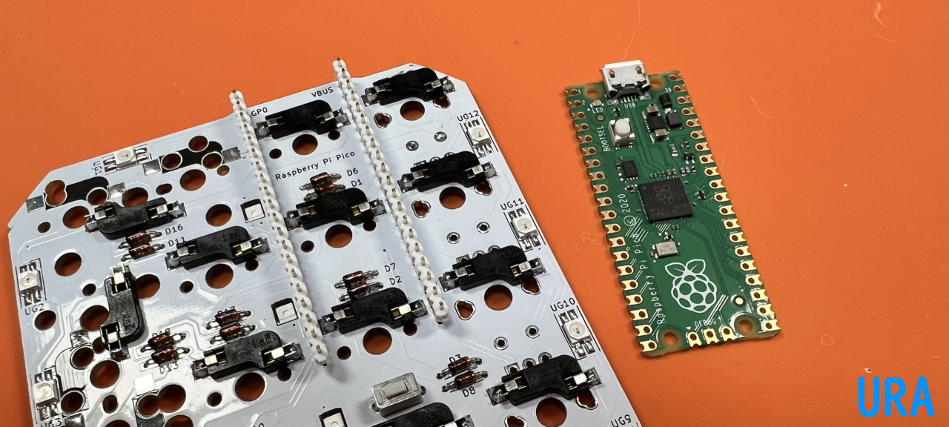
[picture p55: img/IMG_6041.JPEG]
   
Place and soloder the Raspberry Pi Pico. 
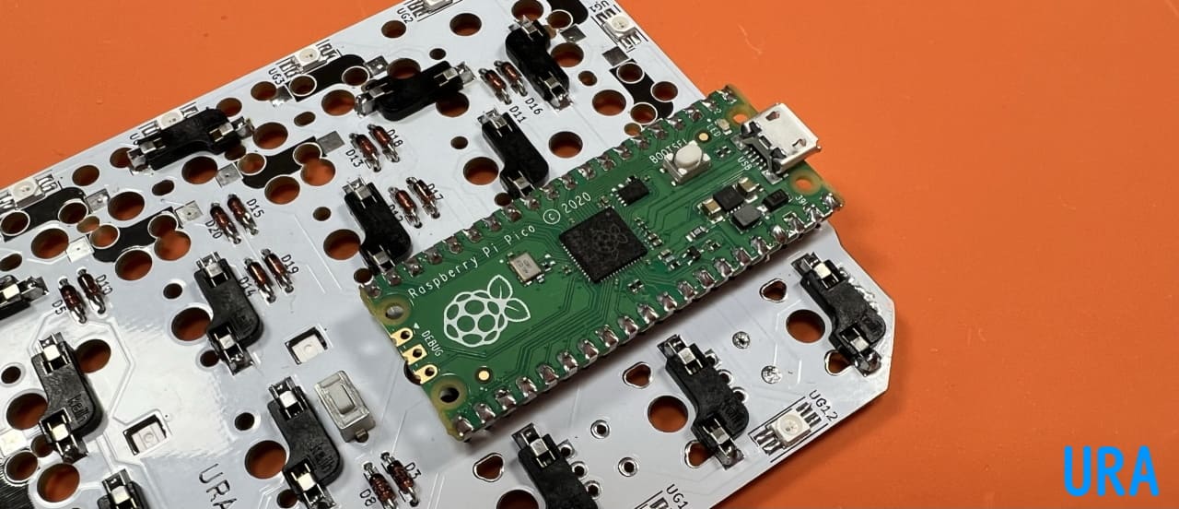
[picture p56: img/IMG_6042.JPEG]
   
Cut and solder the surface legs.  
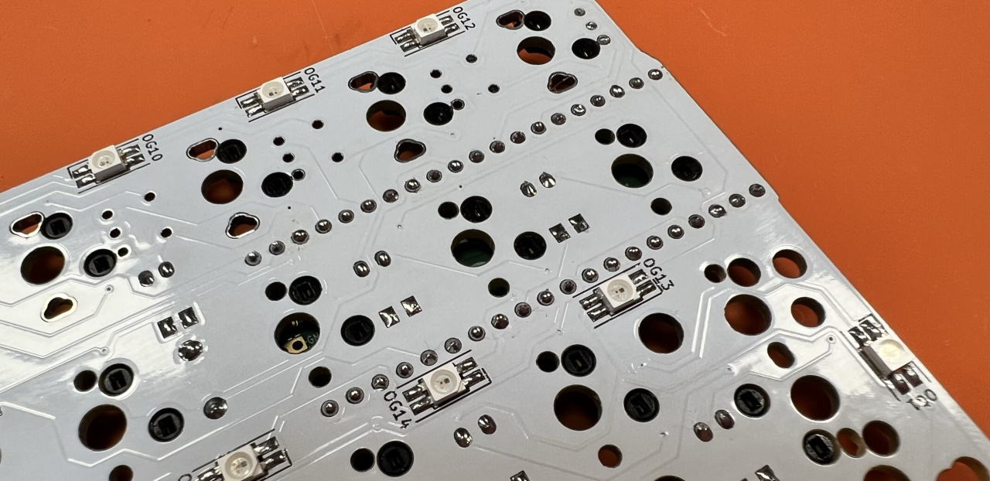
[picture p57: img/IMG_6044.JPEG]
   

### Testing
Plug in the Raspberry Pi Pico and connect it to PC.  
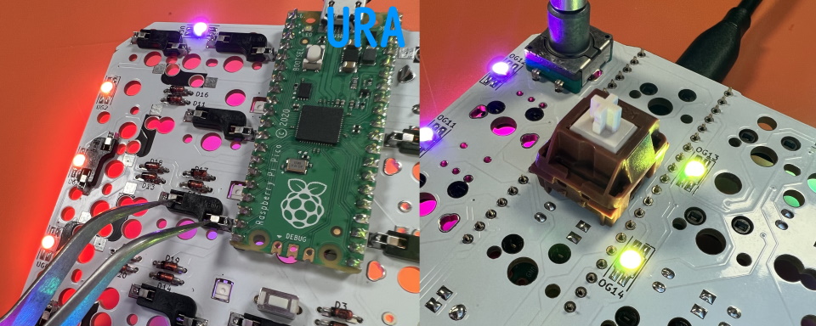
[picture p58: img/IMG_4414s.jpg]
   
   
## Assembling
### Stabilizers
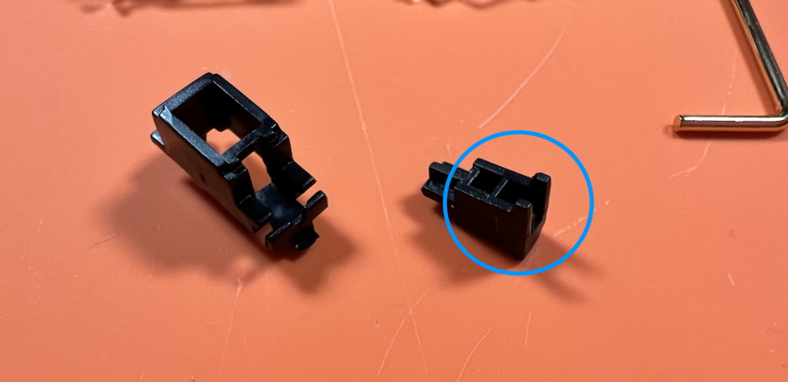
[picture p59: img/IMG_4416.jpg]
  
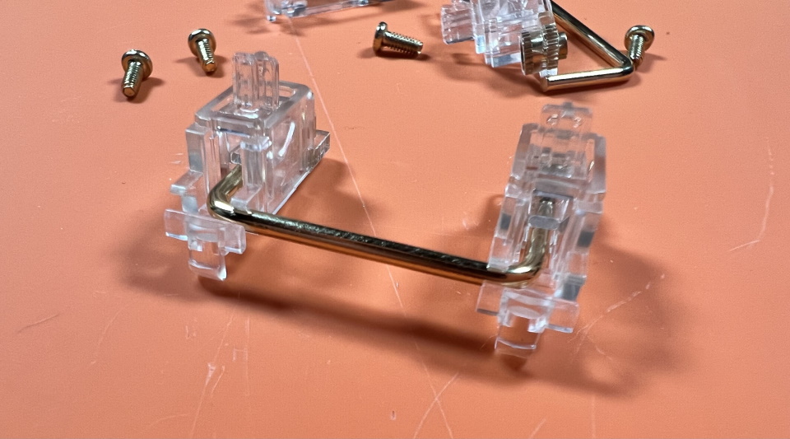
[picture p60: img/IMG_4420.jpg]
    
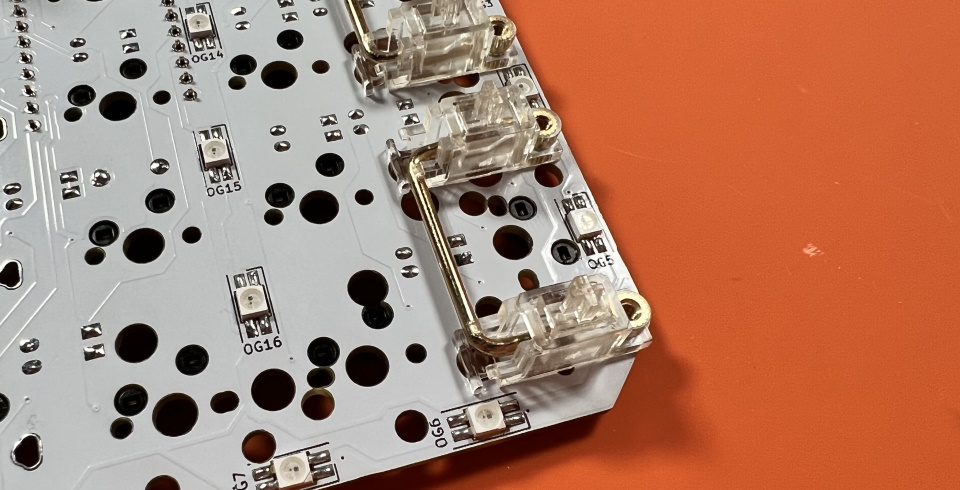
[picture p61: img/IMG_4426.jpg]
   

Cut off the corners of the stabilizer because it would interfere with the acrylic.    
   

### Plates
Place the top plate on the main board.  
  
  
Install Switches.
  
  

Attach spacers with short screws.  
  

Place thicker middle plate #1 and thiner middle plate #2 on it.  
   

Put the middle plate #3.   
  

Fasten the back plate with long screws and put the rubber feet.  
  

Install the Keycaps.
  

Then connect to PC.

## Customise
These Keycodes are avilable.
- https://github.com/Taro-Hayashi/PRKFirmware0.9.7Keycode/blob/main/README_EN.md

Sample keymap from the build manual.
- https://github.com/Taro-Hayashi/Shotgun-CherryPie/releases/download/0.9.8/keymap.rb

### Change keys
Open keymap.rb in PRK Firmware drive.
~~~
kbd.add_layer :default, %i[
  KC_A  KC_B  KC_C  KC_D
  KC_E  KC_F  KC_G  KC_H
  KC_I  KC_J  KC_K  KC_L
  KC_M  KC_N  KC_O  KC_P
  KC_Q  KC_R  KC_S  KC_T
]
~~~

Change KC_* to change keys.  
Overwrite and save to update.  

### Rotary Encoder
~~~
encoder_1 = RotaryEncoder.new(27, 28)
encoder_1.clockwise do
  kbd.send_key :KC_1
end
encoder_1.counterclockwise do
  kbd.send_key :KC_2
end
kbd.append encoder_1
~~~

### Add layer
~~~
kbd.add_layer :lower, %i[
  KC_NO  KC_NO  KC_NO  KC_NO
  KC_NO  KC_NO  KC_NO  KC_NO
  KC_NO  KC_NO  KC_NO  KC_NO
  KC_NO  KC_NO  KC_NO  KC_NO
  KC_NO  KC_NO  KC_NO  KC_NO
]
~~~
Layer key is same as layer name.  

### Tap and hold key
~~~
kbd.define_mode_key :0_LOW, [ :KC_KP_0, :lower, 150, 150 ]
~~~

### Copmposite key
~~~
kbd.define_mode_key :UNDO,   [ %i(KC_Z KC_LCTL), :nil, 150, 150 ]
~~~

### String key
~~~
kbd.define_mode_key :TEST, [ Proc.new { kbd.macro "aaaa" }, :KC_NO, 300, nil ]
~~~
  
Completed. Thank you for your time.  
  

## Misc
### Switch pusher
  

### QMK Firmware
Install qmk uf2 file.
- [shotgun_cp_via.uf2](https://github.com/Taro-Hayashi/Shotgun-CherryPie/releases/download/0.9.8/shotgun_cp_via.uf2)

JSON for Remap/VIA
 - [shotgun_cp.json](https://github.com/Taro-Hayashi/Shotgun-CherryPie/releases/download/0.9.8/shotgun_cp.json)

### Plates data
 - [shotgun_cp_plates.zip](https://github.com/Taro-Hayashi/Shotgun-CherryPie/releases/download/0.9.8/shotgun_cp_plates.zip)  

### Thanks
Used foostan's footprint.  
https://github.com/foostan/kbd/  
https://github.com/foostan/kbd/blob/master/LICENSE  

Used Yoichiro's footprint.  
https://github.com/yoichiro/yoichiro-kbd  
https://github.com/yoichiro/yoichiro-kbd/blob/main/LICENSE 

Sekigon's qmk firmware branch  
https://github.com/sekigon-gonnoc/qmk_firmware/tree/rp2040

PRK Firmware  
https://github.com/picoruby/prk_firmware/

- BOOTH: https://tarohayashi.booth.pm/items/3430753
- Yushakobo: https://shop.yushakobo.jp/en/products/3415

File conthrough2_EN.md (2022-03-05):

## Conthrough

Stand the consule on the back side of the board. No soldering on the board side.   
   
Make sure that the windows of the conthrough are high and facing the same direction.  
  
Place the Raspberry Pi Pico on it.  
   
Solder the Raspberry Pi Pico.  
   
pull out the Raspberry Pi Pico.

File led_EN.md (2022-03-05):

## LED installation
  
Align the notch of the LED with the corner of the silk print.  
    
  
Solder UG1 to UG12.  
    
    

Solder OG1 to OG16.  


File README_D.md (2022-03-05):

# Shotgun チェリーパイ ビルドガイド（[English](https://github.com/Taro-Hayashi/Shotgun-CherryPie/blob/main/README_EN.md)）
※2022年3月販売分からピンヘッダが同梱になり、コンスルーが必須ではなくなりました。  
以前のビルドガイドは[こちら](https://github.com/Taro-Hayashi/Shotgun-CherryPie/blob/main/README_OLD.md)。  
- [キット内容](#キット内容)
- [準備](#準備)
- [はんだ付け](#はんだ付け)
- [組み立て](#組み立て)
- [キーマップのカスタマイズ](#キーマップのカスタマイズ)
- [その他](#その他)

## キット内容
  
||部品名|数| |
|-|-|-|-|
|1|メインボード|1||
|2|トッププレート|1||
|3|ボトムプレート|1||
|4|ミドルプレート1|1|5mm厚|
|5|ミドルプレート2|1|3mm厚|
|6|ミドルプレート3|1|3mm厚|
|7|ネジ（短）|4|4mm|
|8|ネジ（長）|4|8mm|
|9|スペーサー|4|8mm|
|10|ダイオード|20|1N4148|
|11|リセットスイッチ|1||
|12|Cherry MX ホットスワップソケット|20||
|13|ゴム足|4||
|-|40Pピンヘッダ|1||

### キット以外に必要なもの
|部品名|数|||
|-|-|-|-|
|Raspberry Pi Pico|1||[遊舎工房](https://shop.yushakobo.jp/products/raspberry-pi-pico) / [秋月電子通商](https://akizukidenshi.com/catalog/g/gM-16132/) / [共立エレショップ](https://eleshop.jp/shop/g/gL25313/)|
|キースイッチ||CherryMX互換|[遊舎工房](https://shop.yushakobo.jp/collections/all-switches/cherry-mx-%E4%BA%92%E6%8F%9B-%E3%82%B9%E3%82%A4%E3%83%83%E3%83%81) / [TALPKEYBOARD](https://talpkeyboard.net/?category_id=59cf8860ed05e668db003f5d) / [DailyCraftKeyboard](https://shop.dailycraft.jp/collections/mx-switches)|
|キーキャップ||CherryMX互換|[遊舎工房](https://shop.yushakobo.jp/collections/keycaps/cherry-mx-%E4%BA%92%E6%8F%9B-%E3%82%AD%E3%83%BC%E3%82%AD%E3%83%A3%E3%83%83%E3%83%97) / [TALPKEYBOARD](https://talpkeyboard.net/?category_id=59e2acfaed05e644fd004008)|
|Micro-USB ケーブル|1|||

### オプション
|部品名|数|||
|-|-|-|-|
|コンスルー20ピン (高さ2 mmか2.5 mm)|2|[使い方](https://github.com/Taro-Hayashi/Shotgun-CherryPie/blob/main/conthrough2.md)|[遊舎工房](https://shop.yushakobo.jp/products/31?variant=40815837610145) / [共立エレショップ](https://eleshop.jp/shop/g/gKB6127/)|
|スタビライザー|必要数|2U、PCBマウント|[遊舎工房](https://shop.yushakobo.jp/collections/all-keyboard-parts/Stabilizer) / [TALPKEYBOARD](https://talpkeyboard.net/?category_id=5f884b9b3313d216eb50558a)|
|ロータリーエンコーダ|～5|EC11/EC12/ロープロファイル|[遊舎工房](https://shop.yushakobo.jp/search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) / [TALPKEYBOARD](https://talpkeyboard.net/items/5f3f1a597df28129f2fd4b0f) / [DailyCraftKeyboard](https://shop.dailycraft.jp/products/encoder_low) / [Amazon](https://www.amazon.co.jp/s?k=EC11+%E3%82%A8%E3%83%B3%E3%82%B3%E3%83%BC%E3%83%80%E3%83%BC&language=ja_JP)|
|ノブ|～5|外径19mmまで|[DailyCraftKeyboard](https://shop.dailycraft.jp/products/encoder_lowprofile_knob) / [Amazon](https://www.amazon.co.jp/s?k=%E3%82%A8%E3%83%B3%E3%82%B3%E3%83%BC%E3%83%80%E3%83%BC+%E3%83%8E%E3%83%96)|
|SK6812MINI-E|12、もしくは28|12個で裏面のみ、28個で両面になります。|[遊舎工房](https://shop.yushakobo.jp/products/sk6812mini-e-10) / [秋月電子通商](https://akizukidenshi.com/catalog/g/gI-15478/)|

### 必要な工具
|工具名|
|-|
|はんだごて|
|こて先クリーナー（こて台）|
|鉛入りはんだ|
|ピンセット|
|精密ドライバー|
|ニッパー等ダイオードの足を切れるもの|

### あると便利な工具
|工具名|
|-|
|耐熱シリコンマット|
|温度調節可能なはんだごて|
|斜めに切ったタイプのこて先|
|フラックス|
|フラックスリムーバー、IPA|
|テスター|
|マスキングテープ|
|はんだ吸い取り線|
|はんだ吸い取り器|

## 準備
### レイアウトを決める  
このキットはいろいろなレイアウトから選んでお使いいただけます。  
   
色のついているところが交換可能になっています。  
  
ビルドガイドではロータリーエンコーダーを1つ、幅が2倍（2U）のキーを二つ使ったテンキーにします。  
   
キット、その他必要なものに追加でロータリーエンコーダーとノブを一つずつ、スタビライザーを2つ用意しました。  
   

### ファームウェアの書き込み
最新版のPRKファームウェアのzipファイルをダウンロード、解凍します。
 - [Releases・picoruby/prk_firmware](https://github.com/picoruby/prk_firmware/releases)  

Assetsをクリックすると出てきます。
 

Raspberry Pi Picoを、BOOTSELボタン押しながらUSBケーブルでPCと接続すると、RPI-RP2というUSBメモリとして認識されます。  
   
   
そこに解凍したuf2ファイルを書き込むと、自動的に再起動して代わりにPRK Firmwareというドライブとして認識されます。  
   
そのドライブにこちらのkeymap.rbをドラッグアンドドロップするとRaspberry Pi Picoをキーボードとして使えるようになります。 
 - [keymap.rb](https://github.com/Taro-Hayashi/Shotgun-CherryPie/releases/download/0.1/keymap.rb)  

書き込みが終わったら一旦USBケーブルは外します。  

## はんだ付け
はんだ付けのやり方は動画で見るとわかりやすいです。  
パーツは思ったより壊れないので落ち着いて作業すると失敗しにくいです。  
 - ホームセンターのDCMさんの解説動画(58秒～) https://www.youtube.com/watch?v=JFQg_ObITYE&t=58s  
  
### （オプション）LEDのはんだ付け
LEDを取り付ける場合はメインボードに最初にはんだ付けします。  
 - [LEDの取り付け方](led.md)  

後からでも可能ですがホットスワップソケットにこてが当たり溶かしてしまう可能性があります。  

### ダイオード、リセットスイッチのはんだ付け

D1~D20まで取り付けます。  
足を曲げて裏から差し込みます。  
   
ダイオードには向きがあります。三角形の先の棒と黒線を合わせましょう。  
  
表で更に足を曲げて抜けないようにします。  
   
ダイオードと並行に曲げるとあとでキースイッチに干渉しにくいです。 
  
はんだ付けをして足を切ります。  
   

リセットスイッチを裏から差し込み表ではんだ付けします。  
   

### ソケットのはんだ付け
使うソケットのパッドに予備はんだをします。あらかじめ薄くはんだを乗せます。  
    
ソケットを置いたらピンセットで押さえつけながらはんだを注いでいきます。入り組んでいて表面積が多いので多めに必要になります。  
     

青枠の部分にあるソケットは基板になるべく密着するようにはんだ付けしてください。  
   
裏から見ると左右が逆になっているのでレイアウトに注意しましょう。  

### （オプション）ロータリーエンコーダーのはんだ付け
足を折らないようにホールに通します。  
   
クリップの部分ははんだ付けしなくても大丈夫です。  
   

### Raspberry Pi Picoのはんだ付け
ピンヘッダを20ピンずつに切るか折るかします。
   
Raspberry Pi Picoを取り外せなくなるので隠れてしまうダイオードの方向やソケットのはんだ付けを改めて確認してください。  
  
ピンヘッダを基板に立てます。どちら側でも構いませんが長い方を挿しました。
   
GP0、VBUS位置を合わせてRaspberry Pi Picoを乗せ、はんだ付けします。  
   
表面の足を切りはんだ付けします。  
   

### 動作確認
Raspberry Pi Picoを差し込んでUSBケーブルを繋ぎます。
   
ソケットをピンセットで短絡したり、スイッチを挿して押したりしてキーが入力されるか調べます。  
  
問題がなければはんだ付けは終了です。お疲れ様でした。  
  
## 組み立て
### （オプション）スタビライザーの組み立てと取り付け
スタビライザーがあると2Uのキーの押下が安定します。無くても使えるのでお好みでお使いください。  
  
小さい方のパーツの穴が二つ開いている側を、大きいパーツの穴が開いている方向に合わせて組み合わせます。  
  
金属の棒を下の穴に差し込みツメにパチっと音がするまで押し込んで完成です。
    
  
商品によっては防音シートがついています。  
  
角にスタビライザーを付けるとケースと干渉するためニッパーで切り落としています。  
  
両側がツメになっているタイプとねじ止めをするタイプがあります。  
  
ねじ止めだとキーキャップを抜くときに一緒にスタビライザーが抜けてしまうのを防げます。  
  
基板の大きい方の穴にツメをひっかけながら取り付けます。  
  

### プレートの取り付け
傷が付かないように裏返しに組み立てられて梱包されているので一度すべてのネジ、スペーサーを外してください。
アクリルプレートからは保護フィルムをはがします。割れやすいパーツもあるので気をつけてください。  

メインボードにトッププレートを乗せます。裏表、上下左右に気を付けましょう。  
  

隅のキースイッチから差し込んで、トッププレートにツメを咬ませます。  
  

全てのスイッチを取り付けました。  
  
トッププレートは浮いていますが、スイッチのツメに引っかかっているため安定しているはずです。  

裏返して4隅にスペーサーを、ネジ（短）で取り付けます。  
  

ミドルプレート1（5mm厚、穴が長方形に近い）、ミドルプレート2（3mm厚、穴が少し狭い）の順にスペーサーに通します。  
  
Raspberry Pi PicoのUSB端子を避ける時に割れないように気を付けてください。

ミドルプレート3を乗せます。  
  

バックプレートをネジ（長）で組付けてゴム足を4隅に貼ります。  
  

キーキャップを乗せたら組み立ては終了です。
  

早速USBケーブルでPCと接続しましょう。

## キーマップのカスタマイズ
ビルドガイドと同じレイアウトにするのであればこちらをそのまままお使いください。  
 - [keymap.rb](https://github.com/Taro-Hayashi/Shotgun-CherryPie/releases/download/0.9.8/keymap.rb)

最初にダウンロードしたものとファイル名が同じなので気を付けてください。  
同様のテンキーとして使う場合もひな形にすると楽になると思います。  

### キーの変更
PRK Firmwareドライブのkeymap.rbを開きます。  

~~~
kbd.add_layer :default, %i[
  KC_A  KC_B  KC_C  KC_D
  KC_E  KC_F  KC_G  KC_H
  KC_I  KC_J  KC_K  KC_L
  KC_M  KC_N  KC_O  KC_P
  KC_Q  KC_R  KC_S  KC_T
]
~~~
ここのKC_*を書き換えてキーを設定します。  
  
キーコードはこちらに載せていますので参考にしてください（バージョンによって違う可能性があります）。  
- https://github.com/Taro-Hayashi/PRKFirmware0.9.7Keycode  

上書き保存をするとその場で変更が反映されます。  

### ロータリーエンコーダー
~~~
encoder_1 = RotaryEncoder.new(27, 28)
encoder_1.clockwise do
  kbd.send_key :KC_1
end
encoder_1.counterclockwise do
  kbd.send_key :KC_2
end
kbd.append encoder_1
~~~
kbd.send_keyのKC_*を変更すると該当のロータリーエンコーダーのキーが変更されます。  
ロータリーエンコーダーはUSB差込側から順に1～5が割り振られています。  

### レイヤーの追加
~~~
kbd.add_layer :lower, %i[
  KC_NO  KC_NO  KC_NO  KC_NO
  KC_NO  KC_NO  KC_NO  KC_NO
  KC_NO  KC_NO  KC_NO  KC_NO
  KC_NO  KC_NO  KC_NO  KC_NO
  KC_NO  KC_NO  KC_NO  KC_NO
]
~~~
レイヤーの名前を変更したキーマップを追加するとレイヤーが増えます。  
レイヤーの名前をキーコードとして使うとそのままレイヤー変更キーとして使えます。  
  
好きな名前のキーコード名を設定し（例では0_LOW）、長押しでレイヤーを変更するキーにすることもできます。  
~~~
kbd.define_mode_key :0_LOW, [ :KC_KP_0, :lower, 150, 150 ]
~~~

### 同時押しのキーコード
~~~
kbd.define_composite_key :UNDO,  %i(KC_Z KC_LCTL)
~~~
例えばCtrl＋Zであればこのように定義します。  

### 文字列を入力するキーコード
~~~
kbd.define_mode_key :TEST, [ Proc.new { kbd.macro "aaaa" }, :KC_NO, 300, nil ]
~~~
あっているかわかりませんがこう定義するとaaaaが入力されました。  
00キーの場合上の同時押しの方が早かったのでそちらを使っています。  
  
キーの設定が終わったら完成です！  
  
  

## その他
### おまけ
小袋のアクリル片とスペーサーを組み合わせると裏面のボタンを押す治具を作れます。
  
※アクリルの形状は違うことがあります。

### QMKファームウェア
こちらのuf2ファイルをインストールしてください。
- [shotgun_cp_via.uf2](https://github.com/Taro-Hayashi/Shotgun-CherryPie/releases/download/0.9.8/shotgun_cp_via.uf2)

QMKは公式にはRaspberry Pi Picoには対応していません。使用しているQMKファームウェアはせきごん様が独自にRP2040への対応を実現したものです。  
基本的な機能は実装済みのものを配布していますが、ご自分でコンパイルをしたい場合はこちらのページを参考にしてください。  
 - [RP2040対応のQMK(非公式)を動かす](https://scrapbox.io/self-made-kbds-ja/RP2040%E5%AF%BE%E5%BF%9C%E3%81%AEQMK(%E9%9D%9E%E5%85%AC%E5%BC%8F)%E3%82%92%E5%8B%95%E3%81%8B%E3%81%99)
 - [ファームウェアのコード](https://github.com/Taro-Hayashi/Shotgun-CherryPie/tree/main/qmk/keyboards/shotgun_cp)

Remap/VIAを使ってGUIでキーを入れ替えることができます。
 - [shotgun_cp.json](https://github.com/Taro-Hayashi/Shotgun-CherryPie/releases/download/0.9.8/shotgun_cp.json)

### プレートのデータ
 - [shotgun_cp_plates.zip](https://github.com/Taro-Hayashi/Shotgun-CherryPie/releases/download/0.9.8/shotgun_cp_plates.zip)  

発注先のルールに沿ってデータを修正してください。  

### 謝辞
foostan様のフットプリントを流用、改変して使わせていただきました。  
https://github.com/foostan/kbd/  
https://github.com/foostan/kbd/blob/master/LICENSE  

yoichiro様のフットプリントを流用、改変して使わせていただきました。  
https://github.com/yoichiro/yoichiro-kbd  
https://github.com/yoichiro/yoichiro-kbd/blob/main/LICENSE 

せきごん様がGPIO15を使っている場合でも正常に動くようにしてくださいました。  
https://github.com/sekigon-gonnoc/qmk_firmware/tree/rp2040

hasumikin様がPRK Firmwareでロータリーエンコーダーを複数個使用できるようにして、感度も上げてくださいました。  
https://github.com/picoruby/prk_firmware/

### 販売ページ
- BOOTH: https://tarohayashi.booth.pm/items/3430753
- 遊舎工房: https://shop.yushakobo.jp/products/3415

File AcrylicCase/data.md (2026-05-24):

# アクリルプレートの発注について
## 発注先
積層構造に向いた押出材を選べる、遊舎工房さんやEmerge+さんに発注することをお勧めします。  
- [遊舎工房](https://shop.yushakobo.jp/products/lasercut)
- [Emerge+](https://www.emergeplus.jp)  

厚みは3mmです。
## デザインデータ  
- [KiCad](KiCad/)

階層別のデータはパーツを上手く配置すれば他のアクリルパーツと一緒に発注したり、特定の層だけ色を変えたりすることができます。  

問題があった時はご自身で対処してください。  
アクリルプレートのデータ及び注文品はご自由に複製、改変、頒布していただけます。

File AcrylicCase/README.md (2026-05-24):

# Shotgun チェリーパイ アクリル積層ケース
- [ご注意](#ご注意)
- [キット内容](#キット内容)
- [組み立て](#組み立て)
## ご注意
- 組み立てにはShotgun チェリーパイ（[遊舎工房](https://shop.yushakobo.jp/products/3415)、[BOOTH](https://tarohayashi.booth.pm/items/3430753)）のメインボードが必要です。
- スタビライザーは使用できません。
- 自分で発注するとお好きな色のアクリル、ネジで制作可能です。
- キースイッチは5ピンのものがおすすめです。

## キット内容
  
|部品名|数|入手先|
|-|-|-|
|アクリルプレート|[図面データ](data.md)|[遊舎工房](https://shop.yushakobo.jp/collections/services/products/lasercut)、[工房Emerge+](https://www.emergeplus.jp)等|
|4x15mmスペーサー|4|[遊舎工房](https://shop.yushakobo.jp/products/a0800c2?_pos=1&_sid=19dbc8a58&_ss=r&variant=37665435484321)、[ヒロスギネット](https://www.hirosugi-net.co.jp/shop/g/g2404/)|
|8mmM2ネジ|8|[遊舎工房](https://shop.yushakobo.jp/products/a0800n2?_pos=2&_sid=6d67644cd&_ss=r&variant=37665433026721)、[ヒロスギネット](https://www.hirosugi-net.co.jp/shop/g/g102178/)等|
|ゴム足|4|[遊舎工房](https://shop.yushakobo.jp/collections/all-keyboard-parts/products/a0800ur-01-6?variant=37665431060641)、100円ショップ、Amazon等|

### 必要なもの
  
|部品名|||
|-|-|-|
|はんだ付け済みメインボード|キースイッチ|キーキャップ|

### 工具（必要に応じて準備してください）
|工具名||
|-|-|
|精密ドライバー|プラスドライバー、必須|
|静電防止手袋|組み立て中に指紋が付くのを防げます。|
|アクリサンデー ポリケアF70|指紋を拭いたりホコリを付きにくくできます。|
|アクリサンデー 研磨剤|側面を磨いてツルツルにしたり、細かい傷を消すことができます。|

## 組み立て
キットをご購入の場合は仮組みされています。アクリルを発注した場合も一度ケースとして組み立てられるか確認すると安全です。  
プレートの順番がわからなくなった場合はこちらを参考にしてください。
 - [プレート一覧](plates.md)
  
表面のネジを外します。  
  
裏返してスペーサーごと底のプレートを抜き取ります。  
  
ネジを外して底のプレートからスペーサーを取り除いたら保護フィルムを剥がし、ふたたびネジでスペーサーを取り付けます。ネジを締めきらず、スペーサーが浮いている状態にするとここから先の作業が楽になります。  
  
表裏があるので穴の位置に気をつけてください。  
  
保護フィルムを外しつつプレートを乗せていきます。  
  
  
  
  
2層目はメインボードとスイッチで挟み込みます。  
  
  
すべてのプレートを乗せたらネジで止めます。  
  
ゴム足を貼ってキーキャップを取り付けたら完成です。  
  
  

## 販売ページ
- [BOOTH](https://tarohayashi.booth.pm/items/3430753)

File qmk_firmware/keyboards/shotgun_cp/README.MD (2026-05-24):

# Shotgun チェリーパイ
- Manual: https://github.com/Taro-Hayashi/Shotgun-CherryPie/blob/main/README.md
- Yushakobo: https://shop.yushakobo.jp/products/3415?_pos=5&_sid=5bacecdd5&_ss=r
- BOOTH: https://tarohayashi.booth.pm/items/3430753



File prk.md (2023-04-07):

# PRK Firmwareの使い方
## ファームウェアの書き込み
最新版のPRKファームウェアのzipファイルをダウンロードして書き込んでください。
 - [Releases・picoruby/prk_firmware](https://github.com/picoruby/prk_firmware/releases)  

出現したPRK Firmwareドライブにこちらのkeymap.rbをドラッグアンドドロップするとRaspberry Pi Picoをキーボードとして使えるようになります。 
 - [keymap.rb](https://github.com/Taro-Hayashi/Shotgun-CherryPie/releases/download/0.1/keymap.rb)  

### キーのカスタマイズ
PRK Firmwareドライブのkeymap.rbを開きます。  

~~~
kbd.add_layer :default, %i[
  KC_A  KC_B  KC_C  KC_D
  KC_E  KC_F  KC_G  KC_H
  KC_I  KC_J  KC_K  KC_L
  KC_M  KC_N  KC_O  KC_P
  KC_Q  KC_R  KC_S  KC_T
]
~~~
ここのKC_*を書き換えてキーを設定します。  
- キーコード（PRK Firmware Wiki） https://github.com/picoruby/prk_firmware/wiki/Keycodes_ja  

上書き保存をするとその場で変更が反映されます。  

### ロータリーエンコーダー
~~~
encoder_1 = RotaryEncoder.new(27, 28)
encoder_1.clockwise do
  kbd.send_key :KC_1
end
encoder_1.counterclockwise do
  kbd.send_key :KC_2
end
kbd.append encoder_1
~~~
kbd.send_keyのKC_*を変更すると該当のロータリーエンコーダーのキーが変更されます。  
ロータリーエンコーダーはUSB差込側から順に1～5が割り振られています。  

### レイヤーの追加
~~~
kbd.add_layer :lower, %i[
  KC_NO  KC_NO  KC_NO  KC_NO
  KC_NO  KC_NO  KC_NO  KC_NO
  KC_NO  KC_NO  KC_NO  KC_NO
  KC_NO  KC_NO  KC_NO  KC_NO
  KC_NO  KC_NO  KC_NO  KC_NO
]
~~~
レイヤーの名前を変更したキーマップを追加するとレイヤーが増えます。  
レイヤーの名前をキーコードとして使うとそのままレイヤー変更キーとして使えます。  
  
好きな名前のキーコード名を設定し（例では0_LOW）、長押しでレイヤーを変更するキーにすることもできます。  
~~~
kbd.define_mode_key :0_LOW, [ :KC_KP_0, :lower, 150, 150 ]
~~~

### 同時押しのキーコード
~~~
kbd.define_composite_key :UNDO,  %i(KC_Z KC_LCTL)
~~~
例えばCtrl＋Zであればこのように定義します。  

### 文字列を入力するキーコード
~~~
kbd.define_mode_key :TEST, [ Proc.new { kbd.macro "aaaa" }, :KC_NO, 300, nil ]
~~~  

### VIA/Remap対応
- [サンプルのkeymap.rb](https://github.com/Taro-Hayashi/Shotgun-CherryPie/releases/download/0.9.18/keymap.rb)
- [prk-conf.txt（PRK Firmwareドライブに入れてください）](https://github.com/Taro-Hayashi/Shotgun-CherryPie/releases/download/0.9.18/keymap.rb)

その他にもいろいろな機能があるのでPRK Firmwareのwikiをご覧ください。
- https://github.com/picoruby/prk_firmware/wiki/Tutorial_ja

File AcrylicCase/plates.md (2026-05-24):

## プレート一覧
上から順です。1層目以外は表裏があります。  
### 1層目
一枚板で長方形に切り抜かれています。  

### 2層目
一枚板でキースイッチの穴が空いています。  

### 3層目

### 4層目
4〜6枚目の違いは接合部分の位置です。重ねた時に外形が一致するように組み合わせてください。順不同。  

### 5層目

### 6層目

### 7層目
一枚板でリセットスイッチ用の穴が空いています。  


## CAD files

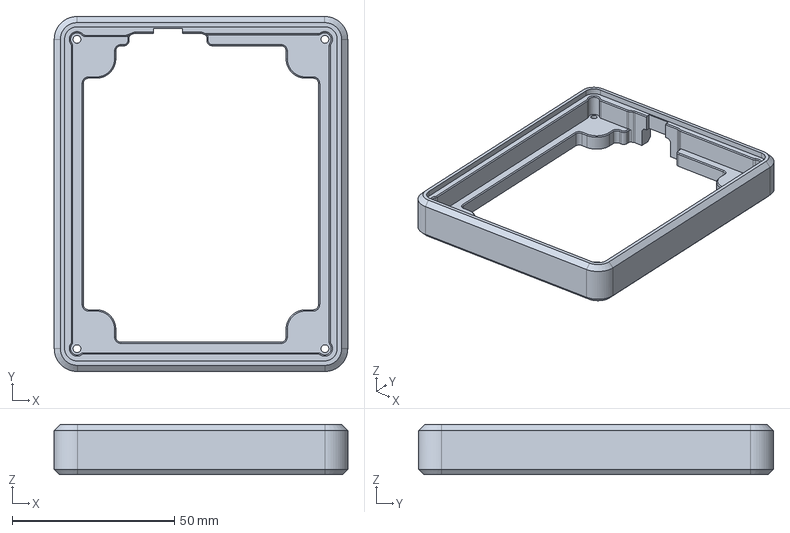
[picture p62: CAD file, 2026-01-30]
step/case.stp
90.6 x 109.6 x 15.5 mm

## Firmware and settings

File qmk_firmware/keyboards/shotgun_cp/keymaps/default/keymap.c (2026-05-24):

// Copyright 2021 Hayashi (@w_vwbw)
// SPDX-License-Identifier: GPL-2.0-or-later

#include QMK_KEYBOARD_H
#include "lib/add_keycodes.h"

enum layer_names {
    BASE = 0,
    LOWER,
    UPPER,
    LIGHT = 5
};

const uint16_t PROGMEM keymaps[][MATRIX_ROWS][MATRIX_COLS] = {
    [BASE] = LAYOUT(
        KC_TAB, KC_PSLS, KC_PAST, KC_PMNS,
        KC_P7, KC_P8, KC_P9, KC_PPLS,
        KC_P4, KC_P5, KC_P6, KC_PPLS,
        KC_P1, KC_P2, KC_P3, KC_PENT,
        KC_P0, KC_PDOT, KC_PDOT, KC_PENT
    )
};

const uint16_t PROGMEM encoder_map[][NUM_ENCODERS][2] = {
    [BASE] =   {
        ENCODER_CCW_CW(KC_A, KC_B),
        ENCODER_CCW_CW(KC_C, KC_D),
        ENCODER_CCW_CW(KC_E, KC_F),
        ENCODER_CCW_CW(KC_G, KC_H),
        ENCODER_CCW_CW(KC_I, KC_J)
        }
};

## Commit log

2022-01-07 0.9.10に対応しました。
2026-01-30 Update section title for 3D printer case
2026-02-05 Update section title for 3D printer case assembly
2026-02-05 Revise 3D printer cover section in README
    Updated section titles and removed redundant heading for 3D printer cover.
2026-02-05 Rename assembly section to '3D Printed Cover'
    Updated the assembly section to reflect the change from '3D Printer Case' to '3D Printed Cover' and adjusted related content accordingly.
2026-05-24 Add acrylic case files
    [shotguncpc_Vanilla.kicad_pcb]
2026-08-02 Fix typo in Raspberry Pi Pico description
